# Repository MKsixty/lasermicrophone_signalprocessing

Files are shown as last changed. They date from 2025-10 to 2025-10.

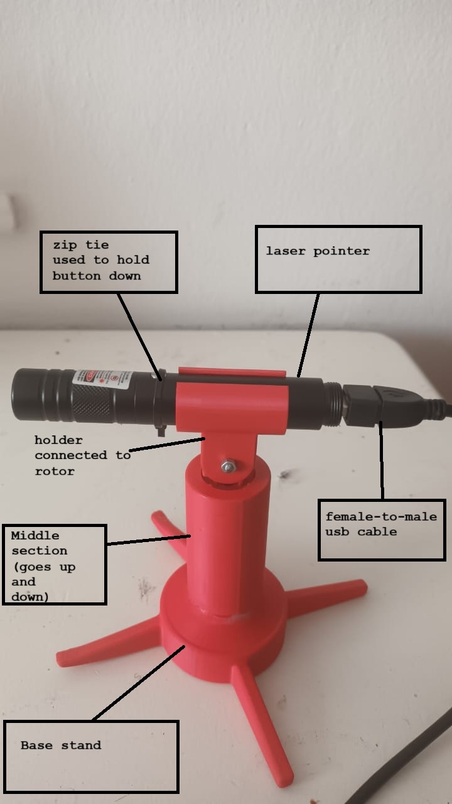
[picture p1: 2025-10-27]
Laser_comp.jpg

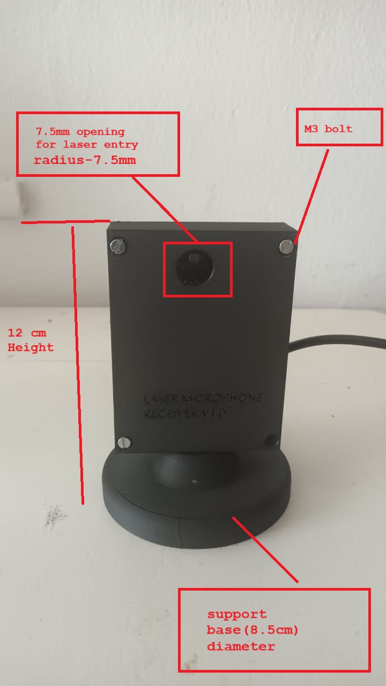
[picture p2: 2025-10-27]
R_front.jpg

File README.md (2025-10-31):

# Laser Microphone Signal Processing Repository

## Overview

This repository contains the complete implementation of a low-cost laser microphone system capable of remotely capturing and reconstructing intelligible speech from vibrating surfaces through optical sensing. The project demonstrates end-to-end acoustic signal recovery using a 650 nm laser transmitter, photodiode-based receiver with dual transimpedance amplifier (TIA) architecture, and multi-stage digital signal processing pipeline.

**Key Achievement**: 15.7-fold intelligibility improvement (STOI = 0.157) with 15.0% Word Error Rate using Whisper Medium transcription on processed audio captured at 1-3 meter distances.

---

## Repository Structure

```
lasermicrophone_signalprocessing/
├── Analysis.m                    # MATLAB signal processing pipeline
├── Laser_MicrophoneV1.py        # Python GUI application with real-time transcription
├── WERcalc.py                   # Word Error Rate calculation utility
├── recordings/                  # Raw and processed audio samples
├── hardware/                    # PCB schematics, 3D models, BOMs
└── docs/                        # Technical documentation and references
```

---

## Hardware Components

### Optical System
- **Transmitter**: BezosMax 650 nm red laser pointer (>5 mW, 2500 m range)
- **Receiver**: BPW34 silicon PIN photodiode (400-1100 nm, 0.6 A/W responsivity @ 650 nm)
- **Reflective Surface**: 3 mm glass window (8.0% reflectivity, superior to Perspex by 0.53 dB SNR)

### Electronics
- **Dual-TIA Architecture**: MCP6292 rail-to-rail op-amps with 10 kΩ feedback resistors
- **Common-Mode Rejection**: Differential amplifier stage (CMRR enhancement for ambient light suppression)
- **ADC Interface**: HiFi USB sound card (48 kHz, 16-bit resolution)
- **Power**: Single 5V USB supply (<500 mA)

### Mechanical
- Custom 3D-printed laser holder with 360° yaw and 90° roll adjustment
- Black PLA receiver enclosure (12 cm height, minimizes optical reflections)

**Total Hardware Cost**: R902 (under R2000 budget constraint)

---

## Software Implementation

### 1. MATLAB Signal Processing (`Analysis.m`)

Multi-stage enhancement pipeline implementing classical DSP techniques:

#### Stage 1: FIR Band-Pass Filtering
```matlab
filter_order = 300;
f_norm = [100 3400] / (fs/2);
b_bp = fir1(filter_order, f_norm, 'bandpass', blackman(filter_order+1));
x_bp = filtfilt(b_bp, 1, x);  % Zero-phase filtering
```
- **Purpose**: Isolate speech band (100-3400 Hz), suppress low-frequency hum and high-frequency sensor noise
- **Window**: Blackman (superior stopband attenuation vs. Hamming/Hann)
- **Implementation**: Zero-phase forward-backward filtering to preserve temporal alignment

#### Stage 2a: Wiener Filter
```matlab
wiener_gain = max(0, 1 - noise_power ./ (frame_power + eps));
wiener_gain = smoothdata(wiener_gain, 'gaussian', 5);  % Musical noise reduction
```
- **Method**: MMSE estimation with noise profile learned from initial 0.5s silence
- **Frame Size**: 20 ms with 50% overlap (Hann window)
- **Smoothing**: Gaussian kernel (5-bin) to suppress musical noise artifacts

#### Stage 2b: Spectral Subtraction
```matlab
cleaned_mag = frame_mag - alpha * noise_spectrum;
cleaned_mag = max(cleaned_mag, beta * noise_spectrum);  % Spectral floor
```
- **Over-subtraction Factor (α)**: 2.0 (aggressive noise removal)
- **Spectral Floor (β)**: 0.001 (prevents excessive attenuation)
- **Window**: Hamming (20 ms frames, 10 ms hop)

#### Stage 2c: Adaptive Spectral Gating
```matlab
snr_estimate = (frame_mag - noise_mean) ./ (noise_std + eps);
gate = 1 ./ (1 + exp(-sensitivity * (snr_estimate - 1)));  % Sigmoid gating
gate = mean(gate_buffer, 2);  % 3-frame temporal smoothing
```
- **Noise Learning**: First 5 seconds (skips initial 30 ms to avoid startup artifacts)
- **Sensitivity**: 2.5 (sigmoid steepness)
- **Soft Gating**: Logistic function for smooth attenuation (vs. hard thresholding)

#### Stage 3: Adaptive Amplitude Restoration
```matlab
% Voice Activity Detection
is_voice = (zcr > 0.03 && zcr < 0.25 && energy > 0.001);

% Gain calculation from original audio
restoration_gain = original_voice_rms / denoised_voice_rms;
restoration_gain = min(restoration_gain, 8.0);  % Limit over-amplification

% Selective amplification
amplified = signal .* (1 + voice_mask * (restoration_gain - 1));
```
- **VAD Criteria**: ZCR ∈ [0.03, 0.25] and energy > 0.001 (25 ms frames)
- **Gain Limiting**: Max 8× to prevent noise re-amplification
- **Normalization**: 99.5th percentile scaling (robust to outlier spikes)

#### Stage 4: Combined Best Approach
Sequential application: Wiener → Spectral Subtraction → Adaptive Restoration
- **Rationale**: Balances smoothness (Wiener), aggressiveness (SpectralSub), and clarity (VAD-based gain)
- **Result**: STOI = 0.157, SNR(VAD) = 3.384 dB, optimal balance across metrics

**Unique Libraries**:
- `signal` (scipy): Butterworth filter design, sosfilt for stable IIR implementations
- `audiowrite`: 48 kHz WAV export for downstream transcription
- `smoothdata`: Gaussian smoothing for musical noise suppression

---

### 2. Python GUI Application (`Laser_MicrophoneV1.py`)

Real-time interface for audio capture, visualization, and transcription.

#### Core Features

**Audio Acquisition**:
```python
stream = p.open(
    format=pyaudio.paInt16,
    channels=1,
    rate=48000,
    input=True,
    input_device_index=device_index,
    frames_per_buffer=1024
)
```
- **PyAudio Integration**: Direct USB sound card interfacing (48 kHz, 16-bit mono)
- **Buffer Management**: 1024-sample chunks for low-latency streaming

**Real-Time Visualization**:
```python
from matplotlib.backends.backend_qt5agg import FigureCanvasQTAgg
self.spectrogram_canvas = MplCanvas(width=8, height=3, dpi=100)
```
- **Waveform Display**: Time-domain amplitude plot with RMS overlay
- **Spectrogram**: STFT-based frequency-time analysis (updated per frame)
- **Dynamic Scaling**: Auto-adjusting axes for signal monitoring

**Speech-to-Text Integration**:
```python
def convert_audio_to_16khz(self, input_file):
    command = ["ffmpeg", "-i", input_file, "-ar", "16000", "-ac", "1", output_file]
    subprocess.run(command, check=True)
```
- **FFmpeg Preprocessing**: Automatic 16 kHz mono conversion for ASR compatibility
- **Multi-Model Support**: 
  - **Vosk** (offline): Small (40 MB), Medium (128 MB), Large (1.5 GB) English models
  - **Google Speech Recognition** (online): Cloud-based via `speech_recognition` library
  - **Whisper** (offline): Small (244 MB), Medium (769 MB) models via `openai-whisper`

**Transcription Workflow**:
```python
model = whisper.load_model('medium')
result = model.transcribe(audio_file, fp16=False)
transcription = result['text'].strip()
```

**GUI Framework**:
- **PyQt6**: Native cross-platform interface with QMediaPlayer for audio playback
- **Tabs**: Recordings management, visualization, transcription settings
- **Configuration**: Device selection, filter parameters, model switching

**Unique Libraries**:
- `pyaudio`: Cross-platform audio I/O (PortAudio wrapper)
- `vosk`: Offline Kaldi-based speech recognition (no internet required)
- `openai-whisper`: Transformer-based transcription (multilingual, robust to noise)
- `speech_recognition`: Google Speech API interfacing
- `matplotlib` + `Qt5Agg`: Embedded plotting in PyQt applications
- `PyQt6.QtMultimedia`: QMediaPlayer/QAudioOutput for WAV playback

---

### 3. WER Calculation (`WERcalc.py`)

Evaluates transcription accuracy using standard Word Error Rate metric:

```python
def calculate_wer(reference, hypothesis):
    ref_words = reference.lower().split()
    hyp_words = hypothesis.lower().split()
    
    # Levenshtein distance via dynamic programming
    d = np.zeros((len(ref_words) + 1, len(hyp_words) + 1))
    # ... matrix computation ...
    
    wer = (substitutions + deletions + insertions) / len(ref_words) * 100
    return wer
```

**Formula**:
$$
\text{WER} = \frac{S + D + I}{N} \times 100\%
$$
where S = substitutions, D = deletions, I = insertions, N = reference word count.

**Usage**:
```python
reference = "the quick brown fox jumps"
hypothesis = "the quack brown fox jumped"
wer = calculate_wer(reference, hypothesis)  # Returns WER percentage
```

---

## Performance Metrics

### Signal Quality (1m Distance, Glass Window)

| Metric | Raw Recording | Combined Processing | Improvement |
|---|---|---|---|
| **STOI** | 0.010 | 0.157 | **15.7× increase** |
| **SNR (VAD)** | 5.305 dB | 3.384 dB | Balanced (post-filtering) |
| **SNR (Noise Floor Est.)** | 14.341 dB | 15.826 dB | +1.485 dB |

### Transcription Accuracy

| ASR Model | Clean Audio WER | Raw Audio WER | Processed WER | Accuracy Gain |
|---|---|---|---|---|
| **Whisper Medium** | 9.09% | 16.46% | **15.0%** | +8.9% absolute |
| **Vosk Large** | 31.2% | 54.79% | 19.16% | +64.98% relative |
| **Google Speech API** | 51.35% | Failed | Failed | Incompatible |

**Key Finding**: Additional Audacity noise reduction (15-17 dB) degraded Whisper Medium performance (21.13% WER), confirming optimal balance achieved by multi-stage pipeline.

### Range Sensitivity

| Distance | SNR (VAD) | STOI | WER (Combined) | Interpretation |
|---|---|---|---|---|
| 1m | 3.384 dB | 0.157 | 15.0% | **Optimal perceptual quality** |
| 2m | 7.531 dB | 0.153 | 15.18% | Balanced |
| 3m | 8.301 dB | 0.085 | 8.11% | **Best ASR (context-driven)** |

**Non-linear Observation**: Higher SNR at 3m due to mean optical power preservation, but STOI degrades from optical diffraction and beam coherence loss. Whisper's language model compensates via contextual inference (lowest WER despite poorest intelligibility).

---

## Installation & Usage

### MATLAB Environment

**Requirements**:
```matlab
% Required Toolboxes:
% - Signal Processing Toolbox
% - Audio Toolbox (for STOI calculation)
```

**Run Processing Pipeline**:
```matlab
% Load recorded audio
[x, fs] = audioread('recordings/1m_glass_raw.wav');

% Load clean reference for SNR/STOI calculation
[clean_ref, ~] = audioread('recordings/clean_reference.wav');

% Execute full pipeline
Analysis;  % Generates stage_1_bandpass.wav through stage_4_combined.wav
```

**Output Files**:
- `stage_1_bandpass.wav`: After FIR filtering (100-3400 Hz)
- `stage_2a_wiener_filtered.wav`: Wiener denoising
- `stage_2b_spectral_subtraction.wav`: Spectral subtraction
- `stage_2c_adaptive_gating.wav`: Adaptive gating
- `stage_3_*_amplified.wav`: Voice-amplified versions
- `stage_4_combined.wav`: **Final optimized output**

### Python Application

**Dependencies**:
```bash
pip install PyQt6 pyaudio numpy matplotlib scipy vosk openai-whisper speech_recognition
```

**FFmpeg Requirement** (for Whisper compatibility):
- **Windows**: Download from [ffmpeg.org](https://ffmpeg.org/download.html), add to PATH
- **Linux**: `sudo apt install ffmpeg`
- **macOS**: `brew install ffmpeg`

**Launch GUI**:
```bash
python Laser_MicrophoneV1.py
```

**Workflow**:
1. **Device Selection**: Choose USB sound card input/output from dropdown
2. **Recording**: Click "Start Recording" → Laser microphone captures audio
3. **Visualization**: Monitor waveform/spectrogram in real-time
4. **Upload Processed Audio**: Load `stage_4_combined.wav` from MATLAB output
5. **Transcription**: Select ASR model (Vosk Large/Whisper Medium recommended) → "Start Transcription"
6. **Export**: Save transcription as `.txt` file

---

## Key Algorithmic Innovations

### 1. Dual-TIA Common-Mode Rejection

**Problem**: Ambient light introduces DC photocurrent offsetting amplifier headroom.

**Solution**: Two TIAs process same photodiode output in opposite polarities. Differential amplifier subtracts common-mode (ambient) while doubling modulated signal:

$$
V_{\text{diff}} = G_d \cdot (V_{\text{TIA1}} - V_{\text{TIA2}}) = G_d \cdot 2 \cdot I_{\text{mod}} \cdot R_f
$$

**Result**: >10 dB ambient noise suppression (CMRR-dependent).

### 2. Hybrid SNR Estimation

**Three Complementary Methods**:

- **Method 1 (Reference-Based)**: Segmented VAD on clean reference, measures residual noise in silence regions after gain compensation
  ```matlab
  snr_ref = 10*log10(signal_pwr_speech / noise_pwr_silence)
  ```

- **Method 2 (Noise Floor)**: First 0.5s assumed noise-only
  ```matlab
  snr_est = 10*log10(mean(signal.^2) / mean(noise.^2))
  ```

- **Method 3 (VAD-Based)**: Energy-based speech/noise classification per frame
  ```matlab
  snr_vad = 10*log10(mean_energy_voice / mean_energy_noise)
  ```

**Insight**: VAD-based SNR most diagnostically valuable—revealed individual filtering stages reduced SNR (1.9-2.6 dB) before adaptive amplification recovered to 3.2-3.9 dB.

### 3. Percentile-Based Normalization

**Problem**: Absolute peak normalization penalizes entire signal for transient spikes.

**Solution**: Use 99.5th percentile of voice regions (identified via VAD) as normalization reference:

```matlab
sorted_voice_abs = sort(abs(voice_signal));
peak_voice_99 = sorted_voice_abs(round(0.995 * length(sorted_voice_abs)));
normalized = signal / peak_voice_99 * 0.98;
```

**Advantage**: Robust to outlier spikes, preserves speech dynamics while preventing clipping.

---

## Hardware Design Files

### PCB Schematics (`hardware/`)
- **KiCad Project**: Dual-TIA receiver with configurable jumpers (JP1-JP4, JPFilter1/2)
- **Gerber Files**: Ready for fabrication (55 mm × 42 mm, 2-layer)
- **Test Points**: TP1-TP6 for oscilloscope debugging

### 3D Models (`hardware/STL/`)
- **Laser Holder**: Base stand, 360° rotor, 90° pitch adjustment
- **Receiver Enclosure**: Black PLA (12 cm height, 7.5 mm photodiode aperture)

### Bill of Materials
- **Electronics BOM**: R902 total (photodiode, op-amps, PCB, USB components)
- **Test Box BOM**: R215 (plywood, glass pane, contact adhesive)

---

## Validation & Reproducibility

### Controlled Test Setup
- **Enclosure**: 20×17.8×25 cm chipboard sound box (sealed with Genkem adhesive)
- **Speaker**: JBL Go 3 (110 Hz - 20 kHz, >85 dB SNR, max volume)
- **Test Audio**: 2-minute monologue from film "Fences" (included in `recordings/clean_reference.wav`)
- **Distances**: 1m, 2m, 3m with fixed alignment

### Objective Metrics
- **STOI**: MATLAB `stoi()` function (0-1 scale, >0.75 = good intelligibility)
- **WER**: Levenshtein distance-based calculation (`WERcalc.py`)
- **SNR**: Three-method validation (reference, noise floor, VAD-based)

---

## Limitations & Future Work

### Current Constraints
- **Range**: 1-3 m operational (optimal 1m for human listening, 2-3m for transcription)
- **Alignment**: Manual beam steering required (no auto-tracking)
- **Processing**: Offline only (MATLAB-based, no real-time embedded DSP)
- **Bandwidth**: 3.4 kHz cutoff excludes sibilants and high-frequency nuances

### Recommended Enhancements
1. **Optical System**:
   - MEMS mirrors or galvanometer steering for adaptive alignment
   - 1550 nm eye-safe laser with silicon APD detection (higher permissible power)

2. **Real-Time Processing**:
   - STM32H7 microcontroller with ARM CMSIS-DSP library
   - Lightweight RNNoise integration for embedded denoising

3. **Advanced Algorithms**:
   - SEGAN (Speech Enhancement GAN) for non-stationary noise
   - Whisper fine-tuning on laser microphone recordings

4. **Environmental Robustness**:
   - Automated calibration via internal reference tones
   - Humidity/temperature compensation for long-term deployment

---

## Citation & Licensing

**Academic Use**:
```bibtex
@misc{mokhakala2025lasermicrophone,
  author = {Mokhakala, Molise},
  title = {Laser-Based Listening Device: Low-Cost Optical Acoustic Sensing with Multi-Stage DSP},
  year = {2025},
  institution = {University of Cape Town, Department of Electrical Engineering},
  url = {https://github.com/MKsixty/lasermicrophone_signalprocessing}
}
```

**License**: MIT (hardware schematics, software code)  
**Hardware Designs**: Open-source (KiCad, STL files freely distributable)

---

## Contact & Support

**Author**: Molise Mokhakala  
**Institution**: University of Cape Town, BSc (Eng) Mechatronics Engineering  
**Supervisor**: Dr. Stephen Paine  

**Issues**: Report bugs or feature requests via GitHub Issues  
**Contributions**: Pull requests welcome for algorithm improvements, ASR model integrations, or hardware optimizations

---

**Acknowledgments**:  
Special thanks to Tsepang (Power Lab technician) for test box fabrication, and Dr. Paine for continuous technical guidance throughout the project.

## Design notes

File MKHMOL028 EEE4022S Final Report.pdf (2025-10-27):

# EEE4022S Research Project

# Final Project Report:

# Laser Based Listening Device

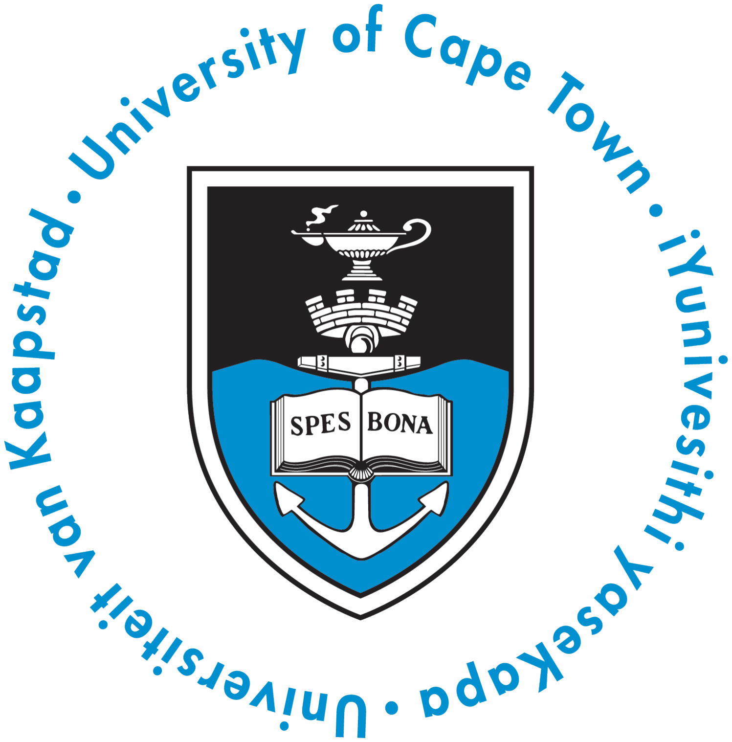
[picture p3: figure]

Prepared by:
Molise Mokhakala

## Prepared for:

Dr Stephen Paine

Department of Electrical and Electronics Engineering

University of Cape Town

Submitted to the Department of Electrical Engineering at the University of Cape Town in partial fulfilment of the academic requirements for a Bachelor of Science degree in Mechatronics Engineering

October 27, 2025

Keywords: laser microphone, optical vibrometry, speech enhancement, transimpedance amplifier, spectral subtraction, Wiener filtering, automatic speech recognition

# Plagiarism Declaration

1. I know that plagiarism is wrong. Plagiarism is to use another’s work and pretend that it is one’s own.
2. I have used the IEEE convention for citation and referencing. Each contribution to, and quotation in, this report from the work(s) of other people has been attributed and properly cited. Any section taken from an internet

source has been referenced to that source.

3. This report is my own work, and is in my own words (except where I have attributed it to others).
4. I have not paid a third party to complete my work on my behalf. My use of artificial intelligence software has been limited to: coding help in VS Code, grammar correction, technical language refinement, and LaTeX formatting assistance.
5. I have not allowed and will not allow anyone to copy my work with the intention of passing it off as his or her own work.
6. I acknowledge that copying someone else’s assignment or essay, or part of it, is wrong, and declare that this is my own work.

Signed:

October 27, 2025

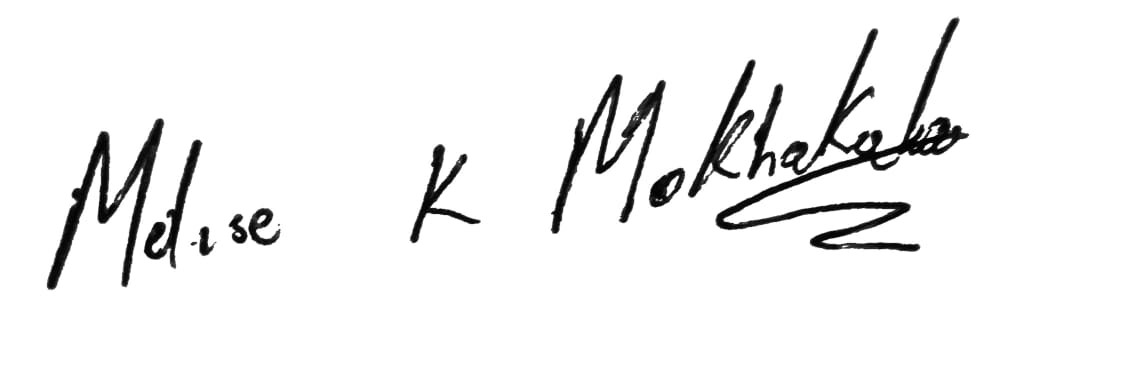
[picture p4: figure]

Molise Mokhakala | Date

Word count: 21793

ii

# Acknowledgements

No man is an island entire of itself; every man is a piece of the continent, a part of the main.
—John Donne

I would like to express my sincere gratitude to Dr. Paine for his continuous guidance, support, and valuable insights throughout this project. His expertise and encouragement were instrumental in its successful completion. I would also like to extend my appreciation to Tsepang, the Power Lab technician student, for his exceptional assistance in developing the test box—an essential component without which none of the experimental results would have been possible

iii

# Abstract

This project presents the design, implementation, and evaluation of a low-cost laser microphone system capable of remotely reconstructing intelligible speech from vibrating surfaces through optical sensing. Sound-induced surface vibrations modulate a 650 nm laser beam reflected from a target window, which is detected by a BPW34 photodiode and converted to electrical signals via a dual transimpedance amplifier (TIA) configuration. The dual-TIA architecture provides enhanced common-mode rejection (CMRR) to suppress ambient light interference,

a critical improvement over single-channel designs. The analog front-end incorporates precision filtering and differential amplification stages, implemented on a custom PCB and powered via a standard 5 V USB interface, achieving a compact and portable form factor suitable for laboratory deployment.

Signal recovery is accomplished through a multi-stage digital signal processing pipeline combining FIR band-pass filtering (100–3400 Hz), Wiener filtering, spectral subtraction, and adaptive voice amplification. This hybrid

approach balances noise suppression with speech preservation, achieving a Short-Time Objective Intelligibility (STOI) score of 0.157—a 15.7-fold improvement over unprocessed recordings. Material characterization revealed that a 3 mm glass window provided 0.53 dB higher SNR than Perspex due to superior optical reflectivity (8.0% vs. 7.8%) and mechanical rigidity. Automatic speech recognition testing using Whisper Medium demonstrated a word error rate (WER) of 15.0% on processed audio at 1 m distance, representing an 8.9% improvement over raw

recordings and validating the system’s practical utility for forensic and surveillance applications.

Range sensitivity analysis at distances of 1–3 m revealed non-linear performance trade-offs: while energy-based SNR increased with distance, perceptual intelligibility (STOI) degraded due to optical diffraction and beam coherence

loss. The system successfully met all design specifications within a budget constraint of R2000, demonstrating that cost-effective laser microphone can achieve sufficient fidelity for automated transcription tasks. The project uses reproducible, open-source implementation integrating modern speech enhancement algorithms with classical optical sensing techniques. All hardware designs, PCB schematics, signal processing code, and experimental datasets are publicly available via GitHub, enabling reproduction and extension by future researchers.It advances the field by providing a reproducible, open-source implementation integrating modern speech enhancement algorithms with classical optical sensing techniques, and establishes quantitative benchmarks for low-cost laser microphone performance across multiple objective metrics.

iv

# Contents

List of Figures | viii
Glossary | ix
1 Introduction | 1
2 Literature Review | 4
3 Methodology | 18
4 System Design and Simulation Analysis | 22

v

Contents

4.2 System Requirements and Specifications | | 22
4.2.1 | Requirements | | 22
4.2.2 | Specifications | | 23
4.3 Design Outline | | 24
4.4 System Overview | | 24
4.5 Hardware Design Process Overview | | 24
4.5.1 | Digitisation and Processing Hardware Comparison | | 28
4.5.2 | Receiver Circuit Implementation — component calculations and selection | | 29
4.5.3 | Mechanical Laser Holder Design | | 33
4.5.4 | PCB Design and Layout | | 34
4.6 Final Hardware Prototype Implementation | | 38
4.7 Testing Methodology and Validation Approach | | 39
4.7.1 | Experimental Setup | | 39
4.7.2 | Measurement Procedure | | 42
4.7.3 | Validation Framework | | 42
4.7.4 | Summary of Methodology | | 42
5 Signal Processing Theory and Implementation | 43
5.1 Overview | | 43
5.2 Signal Model | | 43
5.3 Digital Signal Processing Environment | | 43
5.4 Preprocessing and FIR Band-Pass Filtering | | 43
5.5 Bandwidth Limitation | | 44
5.6 Preprocessing and FIR Band-Pass Filtering in MATLAB | | 44
5.7 Denoising techniques: Wiener and Spectral Subtraction Filtering | | 46
5.7.1 | Wiener Filter Algorithm | | 46
5.7.2 | Spectral Subtraction Algorithm | | 47
5.7.3 | Comparative Evaluation | | 47
5.8 Speech-to-Text Translation | | 49
5.8.1 | Model Selection and Design Rationale | | 50
5.8.2 | Audio Preprocessing for Compatibility | | 50
5.8.3 | Evaluation and Observations | | 52
5.8.4 | more noise reduction | | 52
5.9 Improvement | | 52
5.9.1 | Python Integration and Real-Time Interface | | 52
6 Results | | 54
6.0.1 | Material Comparison: Perspex(Acrylic) vs. Glass Window | | 54
6.0.2 | SNR calculation | | 54
6.1 detection and filtering results | | 55
6.1.1 | method | | 55
6.1.2 | Method:STOI | | 56
6.1.3 | results | | 56
6.2 Speech-to-Text Results | | 58
6.3 Range Sensitivity | | 59

vi

Contents

6.3.1 | Method | | 59
6.3.2 | Results | | 60
6.3.3 | Range Sensitivity Analysis | | 60
7 Discussion | | 61
8 Conclusion | | 63
9 Recommendations | 64
A appendix | | 69
A.1 Code and Data Repository | | 69
A.2 Receiver simulation circuits | | 69
A.3 receiver full pcb schematic | | 69
A.4 Bill of Materials | | 71
A.5 matlab Combined processing code snippet | | 72
A.6 The processing stages waveforms and spectrograms | | 76
A.7 SNR calculation code | | 76
A.8 AI prompts and responses | | 78

vii

# List of Figures

2.1 Laser_beam divergence and convergence due to window vibration | | 5
3.1 The overview of all the project stages | | 18
3.2 Iterative development flow diagram illustrating the requirement-driven progression through design
stages with feedback loops for refinement and validation | 20

4.1 High-level architecture of the laser microphone receiver, showing the optical detection, acquisition,
and DSP subsystems | 24
4.2 Transimpedance amplifier converting photodiode current into a voltage signal for optical-to-electrical
interfacing | 26
4.3 Dual transimpedance amplifier (TIA) configuration used to improve common-mode rejection and
reduce ambient light interference | 29
4.4 Buffered voltage reference and AC-coupled amplifier stage with gain of 2 (20k/10k) using LM358
op-amps. The circuit replacing just the ac coupled buffer | 32
4.5 Exploded render of the 3D-printed mechanical laser holder assembly showing (a) the base stand, (b)
the rotor section, and (c) the laser holder with a firm grip on the 18mm diameter laser case . . . . 33

4.6 the laser holder showing the stand, rotor, and laser mounted together. This set up gives the laser a maximum height of 15cm based on the adjustment of the middle which can be rotated up or down 34 4.7 PCB design views showing the overall layout (left) and detailed layer breakdowns (right). The

configuration highlights the analog front-end placement, ground-plane strategy, and component
accessibility | 37
4.8 Final 3D-printed enclosure and mounting stand for the laser microphone receiver, fabricated from black PLA with a total height of 12 cm and base diameter of 8.5 cm. The labelled features highlight
design details including component alignment, cable routing, and surface openings | 40
4.9 Test setup for validation of the laser microphone receiver: 3 mm glass window mounted on wooden
sound enclosure with internal JBL Go 3 loudspeaker source | 41

5.1 Comparison of time-domain (left) and frequency-domain (right) characteristics for the 1 m test. The

raw audio amplitude is generally lower than the clean reference, except for a spike near 20 s, which reduces the overall audibility of the laser microphone signal. In the spectrogram, the noisy signal maintains higher power levels (70–80 dB, dark blue) up to 3.5–4 kHz for most of the two-minute duration, while the clean reference remains around 50 dB (cyan), indicating high-frequency noise

contamination in the recorded signal | 44

6.1 Signal-to-Noise Ratio (SNR) comparison using three estimation methods: Clean Reference, Noise
Floor, and Voice Activity Detection (VAD) | | 56
A.1 receiver simulation circuit adding the last amplifier stage | | 69
A.2 PCB receiver schematic | | 70
A.3 The waveforms and the spectrogram of all the audio enhancement stages before adaptive amplification 76
A.4 Waveforms and the spectrograms after adaptive amplification | | 76
A.5 creating a table | | 79

viii

List of Figures

A.6 Promp1 | | 79
A.7 Promp1 | | 79
A.8 Promp3 | | 80
A.9 Prompt2 response | | 80

ADC
Analog-to-Digital Converter – A device that converts an analog signal into its corresponding digital represen-

tation.

ASR
Automatic Speech Recognition – A technology that converts spoken language into text using machine learning

or signal processing algorithms.

BOM
Bill of Materials – A comprehensive list of all components required for hardware assembly.

CMRR
Common-Mode Rejection Ratio – A measure of an amplifier’s ability to reject common-mode signals, i.e.,

noise appearing simultaneously on both inputs.

DAC
Digital-to-Analog Converter – A circuit that converts digital values into continuous analog signals.

DSP
Digital Signal Processing – The numerical manipulation of signals, typically using algorithms to enhance, analyze, or transform data.

FIR
Finite Impulse Response – A type of digital filter with a finite duration impulse response, known for linear

phase properties.

He–Ne Laser
Helium–Neon Laser – A gas laser operating typically at 632.8 nm, used for precise optical measurements due

to its narrow linewidth and coherence.

IIR Infinite Impulse Response – A recursive digital filter type that uses feedback to achieve a desired frequency

response.

LD Laser Diode – A semiconductor device that emits coherent light when forward biased.

LDV
Laser Doppler Vibrometer – A non-contact device that measures surface vibration by detecting the Doppler shift of reflected laser light.

PCB
Printed Circuit Board – A board that mechanically supports and electrically connects electronic components

using conductive tracks and pads.

ix

List of Figures

PIN Photodiode
Positive–Intrinsic–Negative Photodiode – A semiconductor light sensor with fast response and low noise

characteristics.

SNR
Signal-to-Noise Ratio – The ratio between the desired signal power and the background noise power, expressed in decibels (dB).

STOI
Short-Time Objective Intelligibility – A quantitative metric (0–1 scale) assessing the intelligibility of processed

or degraded speech signals.

TIA
Transimpedance Amplifier – An operational amplifier circuit that converts input current (from a photodiode)

into a proportional output voltage.

VCSEL
Vertical-Cavity Surface-Emitting Laser – A semiconductor laser that emits light perpendicular to its surface, often used for compact optical systems.

WER
Word Error Rate – A standard metric for evaluating automatic speech recognition accuracy by comparing predicted text to a reference transcript.

Wiener Filter
– An adaptive filter that minimizes the mean-square error between estimated and desired signals, commonly used for noise reduction.

Whisper
– An open-source speech-to-text model by OpenAI designed for multilingual transcription and robust performance in noisy audio.

Window Reflectivity
– The proportion of light reflected from a window’s surface, influencing the strength of optical feedback in laser microphones.

Photodiode
– A semiconductor device that converts light into an electrical current proportional to the incident optical

power.

x

# Chapter 1

# Introduction

This report details the research, design, and development of a laser-based listening device referred to as a laser microphone in the paper, focusing on the hardware, optical, and signal processing components required to reconstruct audio from distant vibrating surfaces. The study aims to implement a functional prototype capable of capturing and processing acoustic information through non-contact optical sensing. The project was undertaken as part of the final year BSc (Eng) Mechanical Engineering degree in the Department of Electrical and Electronic

Engineering at the University of Cape Town.

## 1.1 Background to the Study

Sound detection using light-based methods has become an emerging field of interest due to its ability to capture acoustic information without direct physical contact. Conventional microphones, although effective, are limited by distance, environmental noise, and the need to be close to the sound source.

Laser-based acoustic sensing provides a non-contact alternative by exploiting the minute vibrations induced on a reflective surface by sound waves. A coherent laser beam directed at the surface captures these vibrations through optical interference, which can then be processed into an audible signal. Early research into laser microphones has demonstrated their potential in surveillance, industrial monitoring, and structural diagnostics, but challenges remain to achieve reliable, noise-resistant, and cost-effective implementations.

This project builds on existing research by designing and testing a laser microphone system tailored for remote acoustic signal acquisition. The focus is on creating a practical laboratory-scale prototype capable of detecting and reconstructing speech or sound signals reflected off common surfaces, using photodiode-based sensing and digital signal processing algorithms for reconstruction.

## 1.2 Problem Statement and Objectives of this Study

Problem Statement: Despite decades of development in laser listening technology for covert surveillance and remote acoustic sensing, practical implementations remain constrained by high costs[1], low signal-to-noise ratios

due to weak optical modulation and ambient interference, and limited accessibility for research applications. Existing systems either sacrifice real-world applicability for laboratory sensitivity or require specialised optical equipment beyond typical engineering budgets. This project addresses the fundamental challenge of whether integrated optical-electronic-algorithmic design can achieve transcription-grade speech intelligibility (WER <20%, STOI >0.15) from a low-cost (<R2000) laser microphone system operating at practical distances (1–3 m) on

common reflective surfaces, while maintaining reproducibility through open-source implementation suitable for forensic, surveillance, and academic applications.

### 1.2.1 Problems to be Investigated

The primary issues to be investigated in this study include:

1.3. Scope, Limitations and Assumptions
- Determining the effectiveness of a laser-based microphone system in reconstructing acoustic signals from a vibrating surface.
- Evaluating how different surface materials, distances, and environmental conditions affect signal accuracy and sensitivity.
- Designing an optical receiver system capable of translating laser reflections into usable electrical signals.
- Implementing digital signal processing algorithms for noise reduction, filtering, and intelligible sound reconstruction.
- Implement a transcription model as part of the device.
- Assessing system limitations, including range and surface profile.

### 1.2.2 Purpose of the Study

The purpose of this study is to develop and experimentally validate a laser-based listening device capable of converting surface vibrations into audible signals. The motivation arises from the potential applications of optical acoustic sensing in security surveillance, industrial inspection, and scientific experimentation. By investigating this approach, the study seeks to bridge theoretical understanding and practical implementation of laser vibrometry for acoustic reconstruction.

The significance of this research lies in demonstrating a proof-of-concept that utilises electronic principles, optical sensing, signal processing, and embedded system design to explore an innovative method of sound detection. The outcomes will provide valuable insights into signal quality optimisation, cost-effective design strategies, and environmental robustness for future implementations.

## 1.3 Scope, Limitations and Assumptions

### 1.3.1 Scope

The scope of this project includes:

- Theoretical and experimental investigation of optical vibration detection for sound reconstruction.
- Design and construction of a laser-based sensing system using commercially available components.
- Implementation of analogue front-end circuitry for photodiode signal conditioning.
- Development of digital signal processing algorithms in MATLAB to reconstruct and evaluate the detected

signals.

- Performance evaluation under controlled laboratory conditions and transcription intelligibility.

### 1.3.2 Limitations

The limitations of this study include:

- The experimental setup is limited to short-range indoor measurements (up to a few meters).
- Environmental disturbances such as air turbulence, background light, and mechanical vibrations may affect measurement accuracy.

1.4. Plan of Development
- The project is constrained by the available budget and laboratory resources, with the budget capped at R2000.
- Real-time embedded processing was not implemented in this phase; signal analysis was conducted offline using MATLAB.
- The study assumes a coherent and stable laser source with negligible beam divergence over the test distance.

## 1.4 Plan of Development

The report begins by introducing the underlying principles of optical sound detection and prior research on laser vibrometry and acoustic signal reconstruction. Chapter 2 presents a comprehensive literature review on laser-based sensing systems and relevant digital signal processing techniques.

Chapters 3 and Chapter 4 outlines the methodology adopted for the hardware and optical design, detailing component selection, circuit implementation, and system integration. Chapter 5 discusses the digital signal processing workflow, including noise reduction, filtering, and time-domain signal reconstruction. This chapter also shows implementation of a translation model and its assessment against other models.

Chapter6 then quantifies the system performance across the dectection, signal processing and transcription domains

The report concludes with a discussion of the system’s performance, limitations, and recommendations for further development, including real-time processing and enhanced environmental robustness.

# Chapter 2

# Literature Review

This chapter situates the laser microphone project within a broader research and technological context by surveying the relevant literature. Although the basic concept of recovering sound from optical vibrations has existed for decades, its applications in both security and scientific settings present unique challenges and opportunities. Rather than simply duplicating past designs, this project aims to critically assess existing methods and technologies to inform the development of a system tailored for modern use cases, including remote surveillance, acoustic sensing, and machine learning–based audio reconstruction.

The objective of this review of the literature is therefore not only to outline technical precedents but also to identify the motivations, limitations, and innovations that have shaped this field. Particular emphasis is placed on the challenges associated with optical signal acquisition and noise suppression, especially in uncontrolled environments where ambient disturbances can dominate the true audio signal.

The chapter begins by reviewing existing implementations of laser microphone systems, ranging from intelligencegrade surveillance tools to academic and hobbyist prototypes. Then it delves into the photonic components that form the heart of such systems, namely lasers, photodetectors, and transimpedance amplifiers, highlighting performance trade-offs and noise sources. Following this, a detailed discussion of signal acquisition and processing challenges is presented, with a focus on the nature of optical vibrometry signals and the types of interference commonly encountered in this context.

To address these challenges, Section 5 reviews the traditional filtering and enhancement techniques used in optical audio processing pipelines. This is followed by a review of emerging machine learning–based methods, which promise more adaptive and robust denoising in complex environments. Finally, relevant research sources are cited to provide a roadmap for further exploration and benchmarking, setting the stage for the technical implementation that follows.

In doing so, this chapter aims to provide both a theoretical foundation and practical motivation for the system design choices made in subsequent stages of the project.

## 2.1 Overview and History of Laser Microphones

Laser microphones, also referred to as laser interferometers, laser vibrometers, or laser accelerometers, are non-contact devices that detect vibrations on a surface caused by sound waves. By directing a coherent light beam, typically a laser, onto a reflective surface such as a glass window, minute deflections caused by acoustic pressure modulate the reflected beam. This modulated light is then converted into an electrical signal using a photodetector, effectively reconstructing the original audio waveform [2]. The human voice typically occupies the 300 Hz–3400 Hz range, which falls comfortably within the operational bandwidth of modern laser microphone systems [3].

The concept of transmitting or detecting sound via light predates the invention of the laser. In the 1880s, Alexander Graham Bell developed the photophone, which transmitted speech using a modulated beam of sunlight reflected

2.1. Overview and History of Laser Microphones

from a vibrating diaphragm onto a selenium cell receiver whose electrical resistance varied with light intensity. Bell considered this device even more significant than his telephone, describing it as capable of revealing “discoveries undreamed of just now” [4]. His work laid the foundation for photoacoustic and photothermal detection methods

that underpin modern optical communication and remote acoustic sensing.

The first practical use of light for covert listening emerged decades later in 1947, when Léon Theremin developed the Buran system in the Soviet Union. Instead of a laser, it employed a low-power infrared beam to detect sound-induced vibrations in window glass at distances of up to 500 m. The system, reportedly used by the KGB to surveil U.S., British, and French embassies in Moscow, is widely regarded as the precursor to the modern laser microphone [5]. By the 1990s, advancements in laser diodes, optical detectors, and signal processing revived

interest in laser-based eavesdropping systems, though their popularity later declined with the advent of digital and network-based surveillance technologies.

Operation In operation, laser eavesdropping relies on the fact that acoustic pressure waves cause solid surfaces—such as windows, cups, or walls—to vibrate. When a laser beam is reflected off such a surface, these vibrations induce phase and amplitude modulations in the reflected light. A remote receiver converts these modulations back into an audio signal. According to FCDO Services [1], this allows stand-off listening from distances exceeding 500 m

without physical intrusion, making it a preferred technique for technical surveillance due to its low detectability.

Moses and Trout [4], describe a simplified academic demonstration of this principle, where a low-cost laser pointer

and solar cell were used to reproduce the sound reflected from a vibrating window. In this setup, fluctuations in the curvature of the glass surface altered the divergence of the reflected beam, creating measurable intensity variations at the photodetector. Even minimal window vibrations produced audible signals after amplification, effectively mimicking the operation of professional-grade surveillance systems.

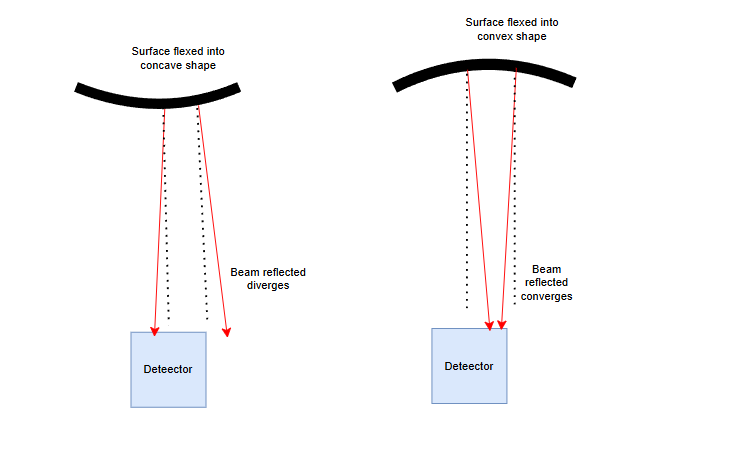
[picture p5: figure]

Figure 2.1: Laser_beam divergence and convergence due to window vibration

Modern laser microphone technology has evolved significantly beyond its espionage origins. Contemporary implementations employ advanced receivers, low-noise amplifiers, and digital demodulation techniques, including double-heterodyne detection, to enhance sensitivity and suppress noise. High-end interferometric systems can now detect sub-nanometer vibrations, with documented sensitivity down to angstrom-scale displacements, and operate under challenging conditions such as fog or poor visibility [6]. Commercial laser vibrometers, originally designed

for precision vibration analysis in engineering and materials testing, are conceptually similar to laser microphones and can be repurposed for acoustic monitoring, structural health assessment, or surveillance applications. .

2.2. Review of Existing Laser Microphone Systems

## 2.2 Review of Existing Laser Microphone Systems

Research into laser microphones has a range of system designs that differ in their underlying optical principles, component choices, and intended applications. Early efforts were closely linked to the development of laser Doppler vibrometers (LDVs), which exploit the Doppler effect to measure vibration velocity from reflected light. Cai [7]

demonstrates that the frequency shift between reference and reflected beams could be directly related to surface vibration velocity, enabling non-contact audio capture. Interferometric techniques such as scanning Laser Doppler Vibrometry (LDV) have also been employed to visualise sound fields non-intrusively by detecting refractive index variations in air [8][9] [10]. Such systems demonstrate the same optical phase modulation principle underlying

modern laser microphones. While LDVs are highly sensitive, their reliance on coherent, mirror-like reflective surfaces limits deployment in practical settings where surfaces are rough or non-ideal. This highlights a recurring trade-off in laser microphone research: systems with high sensitivity often lack robustness in uncontrolled environments.

Alternative approaches leverage pulsed laser vibrometers (PLVs). Wang et al. [11] proposes a pulsed laser system coupled with photo-electromotive force (photo-EMF) sensors, incorporating multiple reflections of the probe beam

to amplify the signal before detection. This design achieved higher sensitivity than conventional vibrometers, but at the cost of increased optical complexity and alignment challenges. The need for stable beam redirection across multiple bounces raises questions about system scalability and robustness outside laboratory conditions.

A third class of designs is based on the self-coupling effect of laser diodes (LDs), where variations in refractive index caused by acoustic pressure modulate the laser’s own wavelength. Daisuke [12] reports that this approach,

using a distributed feedback LD with integrated photodiode detection, provided improved sensitivity compared to traditional vibrometry. Importantly, the self-coupling method reduces the reliance on external interferometers, making it potentially more compact and cost-effective. However, performance still heavily depends on surface reflectivity and environmental stability, raising concerns about reproducibility under different operating conditions.

Commercial systems have also emerged, often marketed as invasive or semi-invasive monitoring devices. For example, Argo’s multi-use infrared stethoscope system incorporates a laser microphone option for room surveillance, offering wide field of view monitoring and AM audio transmission at 840 nm argo. While such designs demonstrate practical integration, their technical specifications—such as wideband coverage and eye safety compliance—are rarely reported in detail, making independent evaluation difficult. Moreover, their use of infrared wavelengths prioritises surveillance robustness over high-fidelity sound reproduction, reflecting a divergence between commercial and academic design priorities.

A further commercial example is the PKI 3000 Laser Microphone by PKI Electronic Intelligence [13]. It employs an eye-safe 1550 nm Class 1 laser (< 10 mW) and an integrated interferometric receiver to extract speech information

from Doppler shifts in the backscattered beam. Unlike earlier systems limited by reflection angle, the PKI 3000 achieves greater angular independence and can operate through closed glass surfaces at distances of 5 – 150 m. The device includes a built-in low-light CCD camera for alignment and selectable bandwidths between 150 Hz – 7 kHz, with analog and digital outputs for recording or monitoring. Though PKI notes higher-end variants (PKI 3100/3200) yield better audio quality, the PKI 3000 demonstrates a practical, field-ready implementation that

integrates optical, electronic, and acoustic processing within a single portable unit, highlighting how commercial designs trade fidelity for deployability.

Across these systems, thematic contrasts emerge. LDV- and PLV-based systems prioritise sensitivity but require ideal reflective surfaces and precise alignment, whereas self-coupling LD systems sacrifice robustness for compactness and lower cost. Commercial implementations emphasize operational feasibility over academic metrics such as

2.2. Review of Existing Laser Microphone Systems

signal-to-noise ratio (SNR) or distortion.The optical source and receiver subsystem largely determines system

performance. Laser wavelength, coherence length, power output, photodetector sensitivity, and bandwidth directly influence SNR, dynamic range, and environmental robustness. While early systems relied on gas lasers for coherence stability, advances in semiconductor laser diodes and integrated photonics now enable more compact, energy-efficient, and eye-safe field-deployable designs

### 2.2.1 Laser Source Selection

Traditional laboratory-grade systems typically employ Helium–Neon (HeNe) lasers at 632.8 nm due to their narrow linewidth and high coherence length, ideal for interferometric detection and phase-sensitive vibrometry [9]. However,

such lasers are bulky and power-hungry, limiting their portability. Modern alternatives favour semiconductor-based sources, including distributed feedback (DFB) and vertical-cavity surface-emitting lasers (VCSELs), which provide

tunable wavelengths, compact form factors, and stable output suitable for self-coupling and heterodyne detection schemes [7], [12].

### 2.2.2 Wavelength Considerations

Several studies emphasise that the type of laser diode employed can significantly affect signal capture fidelity. Distributed-feedback (DFB) laser diodes are commonly used due to their narrow linewidth and wavelength stability, which enhance sensitivity to minute surface vibrations [12]. However, their relatively high cost and power

consumption may limit applicability in compact or low-budget systems. Conversely, standard edge-emitting laser diodes are more cost-effective but suffer from broader linewidths and reduced coherence, limiting their performance in interferometric setups.

The selection of operating wavelength also introduces critical trade-offs. Infrared wavelengths around 850 nm are commonly deployed in commercial systems for surveillance, partly because they balance eye safety, availability of components, and adequate reflectivity across common window glass materials argo. However, studies have demonstrated that longer wavelengths, such as 1550 nm, offer improved eye safety margins for higher power operation, albeit at the cost of reduced efficiency in some photodetectors [14]. Moreover, shorter wavelengths (e.g., 633 nm He-Ne lasers) may achieve higher sensitivity due to reduced speckle size on target surfaces, but their increased scattering makes them less robust in outdoor or turbulent conditions [15]. These wavelength-dependent

trade-offs highlight the absence of a universally optimal solution, with system design often reflecting specific application constraints.

### 2.2.3 Photodetectors and Transimpedance Amplifier (TIA) Design

High-speed photodiodes combined with low-noise transimpedance amplifiers (TIAs) form the core of most laser

microphone receiver architectures. The photodiode must provide sufficient bandwidth to cover the acoustic range (20 Hz–20 kHz) while maintaining a low noise-equivalent power (NEP) for adequate signal-to-noise ratio (SNR). Avalanche photodiodes (APDs) offer internal gain and enhanced sensitivity compared to PIN types but introduce excess multiplication noise and require higher bias voltages [16], [17], [18].

The TIA stage plays a central role in determining overall system noise and stability. As Carter notes, “Noise is a purely random signal that cannot be completely eliminated, but its effects can be minimized through careful circuit design” [19]. In a TIA, dominant sources include op-amp voltage and current noise, as well as the thermal (Johnson) noise of the feedback resistor. According to Carter, “the total output noise is the root-sum-square of the

voltage and current noise contributions,” and the total input capacitance forms a pole with the feedback impedance,

2.3. Signal Acquisition and Noise Challenges

limiting bandwidth and affecting stability [19].

Thus, increasing the feedback resistor improves gain but raises thermal noise, revealing an inherent trade-off between sensitivity, bandwidth, and noise. When coupled with high-capacitance photodiodes, wideband TIAs must balance these parameters carefully. Recent CMOS implementations demonstrate sub-pA/√
Hz noise levels and
MHz-range bandwidths, enabling compact, low-noise front ends for laser-based acoustic sensing [17], [20].

Taken together, the literature reveals that laser microphone component selection involves balancing competing requirements: wavelength choice affects safety, reflectivity, and coherence; photodiode selection trades sensitivity against noise; and TIA design must optimise bandwidth while minimising thermal and shot noise. Despite these

insights, comparative experimental studies remain scarce. Most reports evaluate component choices in isolation rather than benchmarking across full system performance. Consequently, it is still unclear which combinations of laser wavelength, detector type, and amplifier topology yield the most robust results in practical acoustic sensing scenarios. Addressing this gap would require standardised testing protocols that account for both controlled

laboratory conditions and variable real-world environments.

## 2.3 Signal Acquisition and Noise Challenges

Noise reduction remains one of the most critical and persistent challenges in the development of laser microphone systems. The issue arises from the fact that noise sources are highly variable across environments and application contexts, and they often change dynamically over time. As Chen [21] notes, early work on speech enhancement

can be traced back to patents in the 1960s, where analogue implementations of spectral subtraction were first described. Although these methods introduced foundational concepts for suppressing additive noise, subsequent decades have shown that no single approach provides robust performance under all conditions.

A key difficulty is the diversity of noise sources affecting laser microphones. Mechanical vibrations and wind contribute low-frequency distortions, while optical noise is introduced through laser jitter and surface roughness of the reflective target. Electronic noise sources, including thermal noise in photodiodes and shot noise, further degrade the acquired signal. Cai [7] emphasised that surface characteristics strongly affect signal quality: rough or non-uniform surfaces scatter light irregularly, leading to reduced signal-to-noise ratio (SNR) and limiting fidelity at higher acoustic frequencies. Daisuke [22] further reported that many laser microphone systems produce SNRs that

are too low for practical recording, highlighting a significant gap between laboratory feasibility and application-level performance.

Multiple strategies have been explored to address these challenges. Physical approaches, such as increasing the number of microphones in an array, allow for beamforming and spatial filtering [21]. However, in most scenarios

only a single optical channel is available, restricting the use of such methods. Traditional digital techniques, including Wiener filtering and spectral subtraction, offer relatively low computational complexity but introduce trade-offs between noise suppression and speech distortion. For instance, Wiener filters reduce noise effectively under stationary conditions but degrade intelligibility when noise is highly nonstationary [23]. Similarly, spectral

subtraction methods perform well in moderate noise but often produce musical noise artifacts in real-world environments [24].

These limitations underscore an unresolved debate in the literature: whether the focus of laser microphone noise reduction should prioritise intelligibility (e.g., for surveillance applications), fidelity (e.g., for recording and archival purposes), or robustness (e.g., for deployment in uncontrolled environments). Each objective demands different trade-offs in filter design, and attempts to optimise one dimension often degrade another. Chen [21] argues that

2.4. Signal Acquisition and Noise Challenges

this “triple constraint” of noise reduction, intelligibility, and naturalness remains a fundamental bottleneck across speech enhancement systems, and laser microphones inherit this challenge in amplified form due to their inherently low SNR.

Overall, while numerous techniques have been developed to ameliorate noise in laser microphone systems, the literature reveals a persistent gap: few comparative studies evaluate algorithms under standardised benchmarks or realistic field conditions. Without consistent metrics and datasets, it remains difficult to determine which acquisition and filtering approaches best translate from theory to practical deployment.

## 2.4 Signal Acquisition and Noise Challenges

Signal acquisition in laser microphones is uniquely difficult because the desired acoustic signal is typically weak and easily masked by multiple sources of noise. Unlike conventional microphones, which rely on direct pressureto-voltage transduction, laser microphones must infer acoustic vibrations indirectly through optical reflections. This multi-stage process introduces mechanical, optical, and electronic noise, all of which complicate robust audio capture.

### 2.4.1 Noise Sources

Noise in laser microphone systems can be broadly classified into three categories. First, mechanical noise includes vibrations from mounts, air turbulence, or wind, which couple into the reflective surface and distort the recovered signal. Second, optical noise arises from speckle effects, surface roughness, and laser jitter, which cause fluctuations in the reflected beam [7]. Third, electronic noise is generated within the photodetection Cain, including shot

noise, dark current, and thermal noise in photodiodes and transimpedance amplifiers. The combination of these noise sources often results in low signal-to-noise ratios (SNR), a limitation repeatedly cited as preventing laser microphones from achieving recording-quality audio [22].

### 2.4.2 Historical and Conventional Approaches

Noise suppression has been a focus of acoustic research for decades. Chen [21] traced early speech enhancement

methods to Schroeder’s patents on analogue spectral subtraction in the 1960s. While such approaches provided foundational tools for noise removal, they assumed stationary additive noise, an assumption rarely satisfied in real-world optical vibrometry. Subsequent studies demonstrated that single-channel algorithms such as Wiener filtering and spectral subtraction could reduce noise effectively in controlled conditions, but at the expense of introducing speech distortion when the noise environment was nonstationary [23], [24].

Invasive alternatives, such as integrating contact stethoscopes with optical receivers (e.g., Argo surveillance systems argo), have been used as fallback solutions to mitigate signal loss when optical paths are obstructed. While

effective in specific contexts, these designs compromise the defining non-contact advantage of laser microphones, highlighting the difficulty of balancing robustness and fidelity.

### 2.4.3 Methodological Tensions

A persistent tension in the literature concerns the trade-offs between intelligibility, fidelity, and robustness. For surveillance-oriented applications, intelligibility of speech is often prioritised over naturalness of sound, whereas high-fidelity recording applications require preservation of acoustic detail beyond 15 kHz. Chen [21] argued that

these objectives cannot be simultaneously optimised with conventional filtering, leading to what he describes as a

2.5. Filtering and Signal Enhancement Techniques

“triple constraint.” In laser microphones, this problem is exacerbated by inherently weaker signals compared to direct-contact microphones, making traditional techniques less effective.

## 2.5 Filtering and Signal Enhancement Techniques

Filtering and signal enhancement are central to the viability of laser microphones, as they determine whether the weak, noise-corrupted optical signals can be transformed into intelligible audio. Over the past decades, both classical signal processing methods and modern machine learning (ML) approaches have been proposed. This

section critically reviews these techniques, highlighting methodological strengths, contradictions, and research gaps.

### 2.5.1 Traditional Filtering Techniques

Traditional approaches form the first line of defence in most laser microphone systems, typically applied in analogue circuitry or as post-ADC digital processing.

Analog Filtering

Analogue pre-processing stages, such as low-pass, band-pass, and notch filters, are often integrated within transimpedance amplifier (TIA) circuits to suppress high-frequency noise and prevent aliasing prior to digitisation. Cai [7] demonstrated that reducing high-frequency optical jitter using analogue low-pass filtering improved SNR

in laser Doppler vibrometry setups. However, such filtering is inherently rigid, offering limited adaptability to time-varying acoustic or environmental conditions.

## 2.6 Digital Filtering (Post-ADC)

Digital FIR and IIR Filtering

Post-ADC, finite impulse response (FIR), and infinite impulse response (IIR) filters are widely employed. FIR

filters preserve linear phase and are effective for speech-band isolation, while IIR filters are computationally efficient but may distort phase [25]. Case studies using equiripple FIR bandpass designs between 100 Hz and 4.5 kHz demonstrated effective suppression of electrical hum and low-frequency noise [26] . Yet, the computational cost of

high-order FIR filters remains a concern for real-time applications.

Comb and Adaptive Filters

Periodic noise, such as power line hum or mechanical resonances, is often addressed using comb filters or ALE methods. Adaptive notch structures have been shown to eliminate harmonic noise efficiently, but their performance degrades when the target speech signal lies near the noise harmonics, requiring high filter orders [21]. Comb

filters offer a simpler alternative but must be tuned carefully to avoid distorting broadband speech components. MATLAB, SciPy, CMSIS-DSP can be used to implement the aforementioned filters.

Spectral Subtraction and Wiener Filtering

Spectral subtraction, a technique first patented by Schroeder and later expanded in Chen’s work [24], assumes

additive, quasi-stationary noise and removes it by estimating noise spectra during silence. While effective in moderate noise conditions, this approach often produces “musical noise” artifacts in nonstationary settings. Wiener filtering provides a theoretically optimal linear solution in the mean-square error sense, but its performance depends

2.6. Digital Filtering (Post-ADC)

heavily on accurate estimation of noise and speech spectra. Benesty et al. [23] highlighted the trade-off: maximising

noise reduction typically introduces significant speech distortion. Widely linear Wiener filters have been proposed to reduce distortion by exploiting conjugate symmetry in speech signals [27], yet they remain computationally complex. Sager et al. [26] demonstrates that a combination of spectral subtraction and gating with gating used

right after the spectral subtraction, resulted in a significant reduction in noise than when just spectral subtraction is used. This brings.

Kalman and Wavelet-Based Filtering

Kalman filters model the audio signal as a dynamic system and are particularly effective under time-varying noise conditions, but they require accurate state-space models, which are difficult to obtain in optical-acoustic contexts [21]. Wavelet denoising provides a time-frequency localised alternative, excelling at suppressing transient noise

while preserving speech onsets. However, the choice of wavelet basis critically affects performance, and there is little consensus on optimal configurations for laser microphones.

### 2.6.1 Machine Learning-Based Approaches

More recently, machine learning methods have been introduced to overcome the rigid assumptions of traditional filtering.

Deep Neural Networks (DNNs)

Cai [7] proposed a two-stage DNN for laser microphone speech enhancement, separating power and phase

components of the waveform. The model outperformed STFT-based baselines in perceptual evaluation of speech quality (PESQ) and short-time objective intelligibility (STOI). However, it underperformed in log spectral distance (LSD), suggesting limited accuracy in fine spectral reconstruction. The reliance on paired clean and noisy data

also raises questions about generalizability to unseen acoustic conditions.

Convolutional and Recurrent Models

Convolutional neural networks (CNNs) operating on spectrograms have been used for denoising, with Daisuke [22]

demonstrating CNN-based speaker recognition using self-coupling LD microphones. Recurrent neural networks (RNNs) and long short-term memory (LSTM) models capture temporal dependencies in noise, and Cai [7] reported

improved high-frequency reconstruction using LSTMs with cross-entropy loss. While promising, these models face challenges in latency and computational load, making real-time deployment on embedded platforms difficult.

Generative Adversarial Networks (GANs) and Lightweight Models

Speech enhancement GANs (SEGANs) [28] generate clean audio by adversarial training, often producing more

natural-sounding speech than traditional filters. Meanwhile, lightweight RNN-based systems such as RNNoise
[29] combine DSP with small neural networks, enabling real-time noise suppression at low cost. These methods

suggest a pathway toward embedded deployment, but their performance on laser microphone data remains largely unexplored, as most have been validated only on conventional audio datasets.

Traditional filtering remains essential for baseline noise suppression, especially in resource-constrained or low-latency systems. However, their reliance on stationary noise assumptions and rigid filter structures limits performance in complex, real-world acoustic environments. Machine learning models demonstrate superior adaptability and perceptual quality but face challenges of dataset scarcity, computational overhead, and reproducibility. The

2.6. Digital Filtering (Post-ADC)

literature reveals a critical gap: there is no standardised dataset of laser microphone recordings for benchmarking denoising algorithms. As a result, most ML-based studies adapt models from conventional speech enhancement,

which may not capture the unique distortions introduced by optical-acoustic sensing. Bridging this gap will require community-driven datasets and hybrid methods that integrate the interpretability of classical filtering with the adaptability of machine learning.

### 2.6.2 Speech-to-Text Systems

Speech-to-text (STT) systems play a crucial role in forensic and intelligence work, particularly for analyzing

and transcribing covert recordings obtained through hidden microphones, parabolic sensors, or optical systems. Transcription transforms spoken evidence into written form suitable for legal or investigative use, providing a permanent record that can be analyzed linguistically or acoustically [30]. However, conventional manual

transcription—often performed by certified translators or forensic linguists—is time-consuming and vulnerable to human error or perceptual bias, especially when recordings are degraded, multilingual, or captured under challenging acoustic conditions [31].

As Loakes et al. [31] note, covert recordings frequently suffer from overlapping voices, background interference,

or limited frequency response, which complicates manual interpretation and reduces evidential reliability. This has motivated growing forensic interest in Automatic Speech Recognition (ASR) and AI-driven STT systems as

objective tools capable of consistent and scalable transcription. Yet, even advanced ASR systems face persistent challenges such as alignment inaccuracies and the risk of “force-aligning” incorrect transcripts to indistinct speech segments—a critical concern in forensic validation and chain-of-custody integrity.

Modern transcription systems have evolved significantly from analogue audio analyzers to fully AI-driven frameworks capable of synchronized digital processing, real-time captioning, and emotion recognition. Eftekhari [32]

highlights how intelligent STT platforms enhance efficiency in domains such as emergency response and medical diagnostics—capabilities that can be extended to surveillance analysis where rapid transcript generation is essential. Nonetheless, system accuracy remains heavily dependent on acoustic conditions, microphone quality, and training datasets, requiring human verification and linguistic post-editing for evidentiary use.

Comparative evaluations by Matarneh et al. [33] categorize major ASR frameworks—including CMU Sphinx, Kaldi,

HTK, Microsoft Speech API, and Dragon Medical—by their domain suitability. Open-source engines such as Kaldi and CMU Sphinx are favored in research and multilingual applications, while proprietary systems like Google Speech and Dragon Medical excel in domain-specific accuracy and noise resilience. These platforms collectively demonstrate the trade-off between transparency, adaptability, and recognition performance, crucial factors when selecting STT tools for forensic or intelligence contexts.

Beyond classical ASR, end-to-end speech-to-text translation (ST) frameworks have expanded the scope of automated transcription. Chen et al. [34] and Xu et al. [35] identify key advances such as pre-training, data augmentation,

and knowledge distillation—techniques that enhance robustness in low-resource and cross-lingual scenarios typical of real-world surveillance audio. Similarly, Bansal et al. [36] demonstrated that translation models can be trained

directly from raw audio-text pairs using unsupervised term discovery, a promising avenue for multilingual forensic processing where annotated corpora are unavailable.

While technological advances have improved recognition speed and cross-lingual accuracy, transcript readability and evidential clarity remain concerns. Jones et al. [37] observed that automatically generated transcripts are

often harder to read and comprehend than those produced by humans, emphasizing the importance of linguistic

2.6. Digital Filtering (Post-ADC)

post-processing and readability correction before legal submission. Thus, despite their efficiency, current STT systems still require expert review to ensure forensic admissibility and contextual accuracy.

In summary, speech-to-text technology has evolved from experimental recognition systems into a sophisticated toolset for forensic intelligence and surveillance analysis. By integrating traditional acoustic modeling with deep-learning-based transcription, modern systems provide unprecedented scalability and consistency. However, challenges in low-quality audio interpretation, model generalization, and transcript validation continue to limit full automation, underscoring the enduring importance of human oversight in forensic transcription workflows [30], [31], [32], [33], [34], [35], [36], [37].

Table 2.1: Summary of Speech Recognition and Speech-to-Text Methods with Real-World Examples matarneh2017, [38], [39], [40], [41], [42], [43], [44], [45]

System / Method | Model / Ap-proach | Key Features | Strengths / Notes | Examples
Template-Based | Reference template matching [38], [40] | Matches input utterances with stored patterns using dynamic time warping or posterior-based distance met-rics | Simple implementation and interpretable matching; effec-tive for isolated-word recog-nition but limited to small vocabularies and speaker de-pendency | Early IVR sys-tems, CMU Sphinx (legacy)
Knowledge-Based | Rule extrac-tion from linguistic and phonetic fea-tures [33] | Uses manually defined syn-tactic or phonetic rules de-rived from domain data | Interpretable structure, use-ful for specialized domains or low-data scenarios; less scal-able to large vocabularies or continuous speech | Dragon Natu-rallySpeaking (early versions)
Statistical (HMM) | Hidden Markov Mod-els with Gaussian mix-tures [33], [39] | Models temporal variabil-ity and state transitions in speech; MFCC or PLP front-end features | Reliable and robust for real-time ASR; adaptable to new languages via re-training; still forms hybrid back-end in Kaldi and HTK systems | Kaldi, Julius, HTK [42]
Neural Network-Based | DNN / RNN / LSTM acous-tic models [33], [43], [44] | Learns deep hierarchical fea-tures and temporal depen-dencies; enables end-to-end acoustic-to-word mapping | High accuracy for large-vocabulary tasks and real-world speech; effective noise robustness; integration into cloud APIs | Google Speech API, Microsoft Azure Speech [43], [44]
End-to-End Seq2Seq | Encoder–decoder with attention or transform-ers [39], [41] | Directly maps speech wave-forms to text or translation outputs; often pretrained on multilingual corpora | Removes manual alignment and HMM dependency; sup-ports low-resource and mul-tilingual input; strong noise resilience but high compute cost | OpenAI Whis-per, Vosk, Meta SeamlessM4T, SpeechT5 [41]

### 2.6.3 Assessment of Speech-to-Text Models

It is essential to establish objective frameworks for evaluating system performance of STTs. While traditional assessments have focused on qualitative judgments or human transcription accuracy, quantitative metrics such as Word Error Rate (WER), Short-Time Objective Intelligibility (STOI), and Signal-to-Noise Ratio (SNR) now serve as standardized benchmarks for comparing the accuracy, intelligibility, and overall quality of

2.6. Digital Filtering (Post-ADC)

automated transcription systems. These measures are particularly relevant in the context of laser microphone recordings, where acoustic distortions and optical artifacts can significantly affect both intelligibility and recognition accuracy.

Word Error Rate (WER)

Word Error Rate remains the most widely adopted metric for evaluating ASR system performance. WER quantifies transcription accuracy by measuring the minimum number of word-level edits required to transform the hypothesis transcript into the reference transcript. The metric is calculated as:

WER =

S + D + I
N
× 100% | (2.1)

where S represents substitutions, D denotes deletions, I indicates insertions, and N is the total number of words in the reference transcript.

WER provides a normalized measure for comparing recognition systems across datasets and languages. Ali and Renals [46] established foundational methods for WER estimation in modern ASR systems, introducing estimated WER (e-WER) techniques that enable performance prediction without requiring full reference transcripts—an approach particularly valuable in real-time forensic analysis.¹

Recent work by Park et al. [47] and von Neumann et al. [48] refines WER definitions for long-form and multi-

talker scenarios, addressing challenges that frequently arise in extended surveillance or conversational recordings. Meanwhile,Von et al. [48] specifically propose the Diarization-Invariant cpWER (DI-cpWER), a metric designed

to isolate and quantify the effect of speaker attribution errors. Unlike the conventional concatenated minimumpermutation WER (cpWER), which is sensitive to speaker label mismatches, the DI-cpWER corrects these

mismatches to reflect the error rate achievable if speaker labels were perfectly assigned. The difference between cpWER and DI-cpWER thus indicates the proportion of errors arising solely from speaker confusions Itoh et al. Apple Machine Learning Research [49] proposes humanized WER formulations emphasizing readability and accessibility, aligning error measurement more closely with human comprehension. Their solution (human evaluation word error rate)HEWER ignores the use of filler words in its approach different from WER which

ignores punctuation and counts every words that is not identical to the reference as an error.

Short-Time Objective Intelligibility (STOI)

While WER measures textual accuracy, it does not capture perceived speech clarity. The Short-Time Objective Intelligibility (STOI) metric provides a complementary measure focused on the intelligibility of the enhanced speech itself. Developed by Taal et al. [50], [51], STOI evaluates the correlation between clean and processed speech

in the time–frequency domain, yielding scores between 0 and 1, where higher values indicate better intelligibility.

The algorithm divides speech into short frames and computes correlation coefficients between spectral envelopes of the clean (xm(j)) and degraded (ym(j)) signals:

STOI =

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
ρ(xm(j), ym(j)) | (2.2)

where M is the number of frames, J the number of frequency bands, and ρ the correlation coefficient.

1https://github.com/qcri/e-wer

2.7. Environmental and Surface Limitations

STOI has been shown to correlate strongly with subjective listening tests across noise, reverberation, and other degradations. Scores above 0.75 suggest good intelligibility, while values below 0.60 indicate the need for further enhancement. Implementations are available through the MATLAB Audio Toolbox [52] and official open-source resources [53].

Signal-to-Noise Ratio (SNR)

The Signal-to-Noise Ratio (SNR) quantifies the relative strength of the speech signal against background noise, expressed in decibels (dB):
SNR = 10 log10

Psignal
Pnoise
(2.3)

where Psignal and Pnoise denote the power of the clean speech and noise components, respectively.

Ephraim and Malah [54] pioneered a priori SNR estimation, forming the basis of Wiener and MMSE filters used in speech enhancement. Plapous et al. [55] refined these approaches for improved accuracy under non-stationary conditions, while Vondrášek and Pollák [56] demonstrated the influence of voice activity detection (VAD) on

SNR estimation reliability. Input SNR values typically range from –5 dB to 15 dB, improving to 10–30 dB after enhancement—an improvement of roughly 10–20 dB, sufficient for most ASR systems. NIST [57] provides

standardized procedures for measuring SNR consistency across datasets.

Comprehensive Performance Evaluation

As emphasized by Hu and Loizou [58], no single metric reliably captures perceptual quality under all degradation

types. A holistic assessment must therefore combine multiple metrics such as WER, STOI, and SNR, along with subjective listening tests. Rix et al. [59] further standardized perceptual evaluation through PESQ (Perceptual Evaluation of Speech Quality), now widely used for speech quality benchmarking. Interactions between these metrics are nonlinear—systems may achieve high intelligibility (STOI) but still record high WER due to language

model errors, or show SNR gains without corresponding intelligibility improvement due to artifacts. Therefore, multi-metric benchmarking remains essential to guide optimization and ensure reliable performance in forensic and surveillance contexts.

## 2.7 Environmental and Surface Limitations

While the optical and signal processing components of laser microphones have received substantial attention, their performance in real-world environments remains constrained by environmental factors and target surface properties. These limitations are particularly significant because they directly affect the reliability and generalizability of laboratory findings.

### 2.7.1 Surface Reflectivity and Roughness

The accuracy of optical-acoustic transduction depends strongly on the reflective properties of the target surface. Smooth, mirror-like surfaces maximise specular reflection and yield higher signal-to-noise ratios (SNR), whereas rough or diffuse surfaces scatter the incident laser beam, reducing coherence and increasing noise [7]. Rothberg et al. [15] highlighted that speckle effects caused by surface roughness introduce random intensity fluctuations,

complicating phase-based detection schemes such as laser Doppler vibrometry. These effects are particularly problematic for surveillance applications, where the surface cannot be controlled.

2.8. Conclusion

### 2.7.2 Environmental Noise and Turbulence

Environmental factors such as wind, air turbulence, and ambient vibrations impose additional noise sources. For outdoor applications, turbulence alters the refractive index along the beam path, leading to beam wander and amplitude fading [15]. Mechanical vibrations of the laser mount or reflective object also couple into the

acoustic signal, generating low-frequency artefacts. Unlike electronic or optical noise, these disturbances are highly nonstationary, making them difficult to suppress with conventional filtering.

### 2.7.3 Eye Safety and Power Constraints

System performance is further constrained by eye safety regulations. While longer wavelengths (e.g., 1550 nm) allow

higher permissible power levels under IEC laser safety standards, they reduce detection efficiency in silicon-based photodiodes [14]. Conversely, shorter wavelengths (e.g., 633 nm) provide high sensitivity but introduce greater

scattering and potential safety risks. This trade-off forces designers to balance sensitivity, safety, and practicality, often resulting in suboptimal compromises.

The literature consistently acknowledges that environmental and surface limitations pose some of the most significant barriers to the practical deployment of laser microphones. Although controlled experiments often demonstrate promising noise suppression and speech intelligibility, these results rarely translate to uncontrolled settings. Current research gaps include the lack of standardised protocols for testing under turbulence, variable reflectivity, and real-world outdoor conditions. Future work should therefore prioritise hybrid systems that combine optical sensing with auxiliary modalities (e.g., inertial or contact sensors) to ensure robustness against environmental disturbances.

Without addressing these limitations, even the most advanced filtering algorithms cannot guarantee reliable field performance.

## 2.8 Conclusion

This review surveyed the evolution of laser microphones from Bell’s 1880s photophone through Theremin’s 1947 infrared system to contemporary semiconductor implementations achieving sub-nanometer sensitivity [6]. Modern

systems integrate distributed feedback lasers, low-noise transimpedance amplifiers, and digital signal processing, yet performance remains heavily surface- and environment-dependent, with significant sensitivity–robustness–cost trade-offs.

Component selection involves critical design choices: wavelength determines the balance between eye safety (1550 nm), photodetector efficiency (650–850 nm), and environmental robustness [14], [15]. Dual-TIA architectures

enhance ambient light rejection through common-mode suppression, although their experimental validation remains limited. Signal processing spans two paradigms: traditional techniques (FIR filtering, Wiener, spectral subtraction) provide real-time efficiency but assume stationary noise [23], [24], [26], while machine learning (DNNs, RNNs) offers superior adaptability [7], [29] at higher computational cost. Hybrid architectures combining classical preprocessing

with lightweight neural networks represent a promising compromise.

Speech-to-text integration enables objective evaluation via WER, STOI, and SNR [46], [51], [54], revealing non-

linear metric relationships—high STOI does not guarantee low WER, and SNR gains may not directly improve intelligibility [58]. Therefore, comprehensive multi-metric evaluation remains essential for assessing overall system

performance.

Priority research gaps include:

2.8. Conclusion
1. Development of standardized benchmark datasets capturing diverse surfaces, acoustic conditions, and noise profiles.
2. Systematic real-world characterization of performance under turbulence, variable reflectivity, and environmental interference.
3. Quantitative cost–performance analysis to inform economically viable designs.
4. Exploration of hybrid architectures integrating complementary sensing modalities (e.g., inertial sensors) for

enhanced robustness.

In summary, the literature reveals that while individual subsystems—optical, electronic, and algorithmic—have advanced considerably, their integration into a cohesive, low-cost, and field-deployable system remains limited. This project directly addresses these gaps by implementing a dual-TIA receiver, a combined FIR–Wiener–spectral subtraction processing pipeline, and a multi-model ASR evaluation framework. Emphasizing cost-effectiveness (R2000 constraint), open-source reproducibility, and quantitative multi-metric assessment, the ensuing chapters

transition from theoretical exploration to practical realization, demonstrating how laser vibrometry can achieve intelligible, transcribable audio reconstruction within realistic design constraints.

# Chapter 3

# Methodology

This chapter outlines the methodological framework adopted for the design, simulation, and experimental validation of the laser microphone system. The approach is structured into five interdependent stages, ensuring a systematic and iterative development process from conceptualisation to final prototype validation.

Each stage built upon the findings of the previous one to refine both the hardware and signal-processing aspects of the system.

## Stage 1 – System Design and Simulation

The first stage involved the conceptual and analytical design of the laser microphone system. System requirements are defined through an assessment of acoustic sensing principles, optical reflection behaviour, and photodetector response. Then a block-level architecture is developed to establish the interaction between the optical transceiver, the analog front-end, and the digital signal processing (DSP) subsystems.

Optical and electronic subsystems are simulated using LTspice to model expected signal behaviour, frequency response, and noise performance. The simulations provided quantitative insight into the relationship between laser beam modulation and detected voltage variation, enabling the determination of design parameters such as photodiode sensitivity and pre-amplifier gain.

Stage 1.1 – Breadboard Testing and Iteration

Following initial simulations, a series of breadboard prototypes are constructed to validate the theoretical models. The optical alignment, photodiode biasing, and amplifier stages are tested incrementally. Each configuration is evaluated in terms of signal clarity, frequency response, and susceptibility to ambient light interference. The results of this phase informed iterative refinements of the circuit topology and component selection, ensuring system stability before PCB implementation.

## Stage 2 – PCB Design

Once the circuit functionality is verified on the breadboard, the design is translated into a printed circuit board (PCB) using Kicad 9.0. Emphasis is placed on minimising noise coupling through careful component placement,

Figure 3.1: The overview of all the project stages trace routing, and ground-plane segmentation. Design-for-manufacturability (DFM) principles are applied to

ensure compactness and ease of assembly. Failure precautions are implemented at each stage to ensure the overall functionality of the system if one section fails.

## Stage 3 – PCB Testing and Validation

After fabrication and having received the delivery of the PCB, it underwent a comprehensive testing procedure. Continuity tests using U3401A (digit dual display Multimeter) are performed to verify electrical integrity, followed

by subsystem-level functional testing. Signal integrity is assessed using the DS0-X-2002A oscilloscope and spectrum analyser to confirm the expected frequency response and noise floor. Any deviations from simulation results are analysed to identify potential layout or grounding issues, allowing for specific rework where needed.

## Stage 4 – DSP Development and Integration

The fourth stage focused on developing the digital signal-processing algorithms necessary for converting the detected analogue signal into a clear audio output. MATLAB and Python are used to implement and test algorithms, including filtering, noise suppression, and amplitude normalisation. The optimised DSP routines are then implemented on a Python app localised on a PC. Synchronisation between the optical detection hardware and DSP system is verified through controlled acoustic tests.

## Stage 5 – Final Prototype and Validation

In the final stage, the complete laser microphone prototype is assembled, integrating all mechanical, optical, and electronic subsystems. The system is evaluated under controlled acoustic conditions to assess its sensitivity, frequency response, and distortion performance. Results are benchmarked against theoretical predictions and ideal acoustics recovery to verify design validity. Observations from this validation phase informed recommendations for further optimisation and field deployment.

The iterative process employed throughout this research follows a systematic cycle designed to ensure robust validation at each development stage shown. Beginning with a comprehensive literature review, each stage proceeds through its defined objectives before undergoing rigorous testing and validation. At decision points, the system’s performance is evaluated against predetermined requirements. If these requirements are not met, the process loops back to the previous stage for refinement and retesting, incorporating lessons learned to address identified deficiencies. Only upon successful validation does the development advance to the current stage, where the same cycle of implementation, testing, and requirement verification is repeated. This feedback mechanism ensures that design flaws and performance limitations are identified and resolved before progressing to subsequent stages, thereby preventing the propagation of errors through the development pipeline. Should the current stage fail to meet its requirements, the iteration continues until satisfactory performance is achieved, at which point the process advances to the next stage. This structured approach minimises the risk of fundamental design issues emerging late in the development cycle and ensures that each subsystem—from initial simulation through to final prototype validation—performs reliably before being integrated into the complete laser microphone system. The details on validation and testing are provided at each stage.

Ethical Considerations Ethically, all test audio consisted of publicly available material or synthesised speech, with no recordings of private conversations or identifiable individuals. The system was operated exclusively within

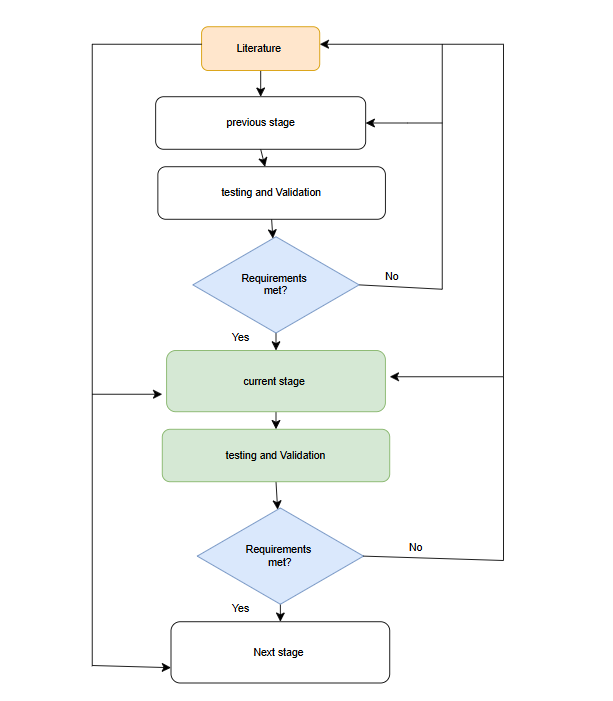
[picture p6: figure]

Figure 3.2: Iterative development flow diagram illustrating the requirement-driven progression through design stages with feedback loops for refinement and validation the university laboratory under controlled conditions, with no field surveillance testing conducted, complying with UCT’s ethical guidelines for engineering projects that do not involve human subjects research or covert monitoring applications.

# Chapter 4

# System Design and Simulation Analysis

This chapter presents the detailed design and simulation analysis of the laser microphone system. The design process is carried out iteratively, where simulation results guide hardware refinement and component selection. The approach ensured that both the optical and electronic subsystems are optimised for performance, stability, and manufacturability. The primary goal is to develop a reliable, low-noise, and compact system capable of reconstructing sound from optical reflections with high fidelity.

## 4.1 Overview

The laser microphone system operates on the principle of detecting sound-induced surface vibrations using an optical beam. A continuous laser is directed onto a reflective surface, and acoustic pressure variations cause minute displacements that modulate the reflected beam’s intensity on the chosen optical receiver. This optical modulation is captured by a photodiode and transformed into an electrical signal, which is then processed through analogue amplification, filtering, and digital signal processing (DSP). The complete system is powered via a standard 5 V

USB supply from the PC, making it portable and compatible with typical laboratory environments.

## 4.2 System Requirements and Specifications

The development of the laser microphone system begins with a clear understanding of its design expectations and operational constraints. These requirements establish the foundation for a reliable and functional system, ensuring that the design objectives are met during both simulation and prototype validation. This section defines the system requirements and corresponding specifications that guided the design process.

### 4.2.1 Requirements

Table 4.1 illustrates the user and functional requirements identified for the laser microphone system.

Table 4.1: Requirements for the Laser Microphone System

REQ-ID | Description
REQ-01 | The system must be low-cost.
REQ-02 | The system must operate using a 5 V DC supply provided via a standard type A USB 2.0 port.
REQ-03 | The system must be capable of capturing sound remotely through a reflected laser beam.
REQ-04 | The recorded audio output must be intelligible and comparable to the reference sound source.
REQ-05 | The system design must require minimal user alignment and setup.
REQ-06 | The complete setup should be compact, portable, and suitable for laboratory-scale testing.

The requirements listed above define the performance expectations of the laser microphone system and form

4.2. System Requirements and Specifications

the foundation for the subsequent specification and design phases. They ensure that the final prototype meets functional, operational, and usability targets while remaining low-cost and reproducible.

### 4.2.2 Specifications

Based on the analysis of the requirements tabulated above, Table 4.2 illustrates the detailed system specifications addressing each requirement, along with the corresponding acceptance criteria that must be met.

Table 4.2: Specifications for the Laser Microphone System

SPEC-ID | Description | REQ-ID | Acceptance Criteria
SP-01 | The system must use a red or infrared laser diode (650 nm–1400 nm) to de-tect sound-induced vibrations from re-flective surfaces at long range. | REQ-03 | Verify that surface vibrations produce measurable signal modulations at the photo receiver output at a minimum of 1 m distance between the receiver and vibrating surface.
SP-02 | The optical receiver must convert reflected light intensity variations into voltage signals using a tran-simpedance amplifier. | REQ-03, REQ-04 | Validate the analogue output for a range of vibration amplitudes and fre-quencies (100–20 000 Hz).
SP-03 | The analogue front-end must provide low-noise amplification and band-pass filtering for 100–18 000 Hz. | REQ-04 | Measure the SNR of the audio file, and it must be within 85% of the SNR of the ideal sound.
SP-04 | The system must interface with a USB sound card for digitisation and PC-based DSP processing. | REQ-02, REQ-04 | Confirm that the recorded signal can be acquired at 44.1 kHz, 16-bit resolu-tion in MATLAB.
SP-05 | MATLAB-based DSP must recon-struct intelligible audio using spectral subtraction and filtering. | REQ-04 | Evaluate processed signal clarity and confirm speech intelligibility above 85%.
SP-06 | All system components must operate on a single 5 V USB power source. | REQ-02 | Measure total current draw and confirm current consumption below 500 mA.
SP-07 | The total prototype cost must not ex-ceed R2000. | REQ-01 | Validate the cost by summing all pur-chased components within the ap-proved bill of materials.

The specifications outlined for the laser microphone system serve as a guide for design and implementation, ensuring that all requirements are met. Each specification is directly traceable to a corresponding requirement, providing measurable performance targets for verification and validation during testing.

4.3. Design Outline

## 4.3 Design Outline

The system design is also structured into three primary domains—optical, analogue, and digital—each fulfilling a specific role in the detection and reconstruction of sound. The optical subsystem provides remote vibration sensing through laser reflection, the analogue front-end ensures low-noise signal conditioning, and the digital signal-processing (DSP) subsystem reconstructs the audio signal through real-time computation. Figure ?? presents

the complete system architecture, highlighting the interaction between these domains.

## 4.4 System Overview

The laser microphone system operates on the principle of optical modulation caused by surface vibrations. When the laser beam reflects off a vibrating surface, the returning light undergoes slight intensity variations proportional to the acoustic signal present on the surface. To extract the embedded information, the reflected beam is detected, converted to an electrical signal, and processed to recover the original sound waveform.

Figure 4.1 illustrates the high-level architecture of the receiver subsystem. The system is divided into three main subsystems:

- Optical and Signal Conditioning Module — captures the reflected light and converts it into a conditioned electrical signal using a photodiode and amplification circuitry.
- Data Acquisition Module — digitises the conditioned analogue signal via a USB sound card or ADC for further processing.
- Digital Signal Processing (DSP) Module — performs demodulation, filtering, and spectral enhancement

to reconstruct intelligible audio from the detected signal.

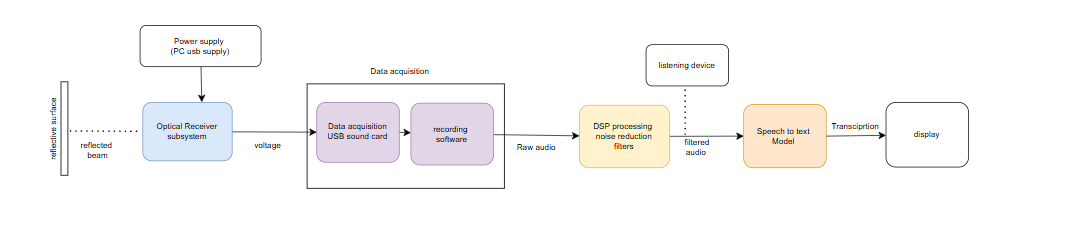
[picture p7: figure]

Figure 4.1: High-level architecture of the laser microphone receiver, showing the optical detection, acquisition, and DSP subsystems.

## 4.5 Hardware Design Process Overview

Following the description of the system design and requirements, it is essential to select hardware components that satisfy the design objectives outlined in Chapter ??, while minimising noise during the retrieval of the modulated signal. This section details the hardware selection process, focusing on component suitability, electrical compatibility, and noise performance.

4.5. Hardware Design Process Overview

Laser Module

A red dot laser module operating in the visible range (λ ≈ 650 nm) is selected as the optical transmitter for this project due to its practicality, visibility, and ease of alignment during laboratory testing. Although infrared (IR)

lasers offer greater discretion for surveillance applications, their invisible beams complicate alignment and safety verification in an experimental setting. The visible red beam, on the other hand, enables precise targeting of the reflective surface and provides immediate visual feedback, significantly reducing setup time and alignment errors.

The selected red dot laser module offers stable optical output power, a compact form factor, and low cost, making it an ideal choice for the prototyping stage of the laser microphone system. Furthermore, the system architecture remains compatible with future adaptation to infrared operation, requiring only replacement of the laser source without major modification to the receiver or signal-processing stages. The datasheets of the following candidate modules are reviewed to evaluate output stability, current consumption, and optical parameters, ensuring compliance with the specifications outlined in Table ??.

To determine the most suitable laser source for the prototype, three candidate transmitters are evaluated in terms of optical performance, electrical compatibility, and practical usability. Table ?? summarises the comparison of these options, highlighting key parameters such as wavelength, output power, operating voltage, and cost.

Table 4.3: Comparison of Laser Transmitter Options

Component / Feature | KY-008 | ROHM RLD65NZX1-00A | BezosMax red laser Pointer
Wavelength | 650 nm (Red) | 663 nm (Red) | 650 nm
Output Power | 5 mW | Up to 10 mW | >5 mW
Beam Range | 18 m under suitable conditions | Medium-range (tens of meters) | Up to 2,500 m
Operating Voltage | 5 V DC | 2.3 V DC typical | USB-C rechargeable
Package / Size | 24mm × 15 mm, 3-pin module | TO-56 metal can, 3-pin | Handheld laser pointer with star cap and USB Type A male connector
cost(ZAR) | 17.00(DIY electronics) | 436.80(RS Components) | 199(takealot)

RLD65NZX1-00A is not used because of the cost and the requirement to build a dedicated laser driver to ensure a

stable output, as this would introduce more complexities into the design. Ky008 and the Bezomax laser pointer are lab tested on their reflectivity at 1 meter distance on a 3mm window pane glass in the setup as described in section section 4.7. ky008 could not be reflected at 1 1-meter distance, but can be reflected 10cm. While the Bezomax laser pointer is effectively reflected, even at 2m. Thus, given that the laser microphone, which requires a long range distance, the primary limitation of the BezosMax pointer is rapid battery depletion during testing. To address this, a 1m female-to-male USB cable is acquired. With the female part connected to the laser, the PC could supply the laser with constant power with a range of motion.

The difference in reflectivity can also be attributed to beam optics. The KY-008 is a bare module without an integrated lens system, so its beam is less uniform and less focused. The BezosMax pointer, in contrast, is packaged as a handheld pointer with built-in optics that produce a well-collimated beam, improving reflection over longer distances. Thus, the bezomax pointer is opted for use, and all the following processes considered it to be the main transmitter.

optical receiver

Based on the selection of the 650 nm laser module, an optical receiver is designed to operate within the laser wavelength and the acoustic frequency range. The optical receiver forms the critical interface between the optical and electrical domains of the laser microphone, converting modulated light reflections into electrical signals for amplification and processing.

4.5. Hardware Design Process Overview

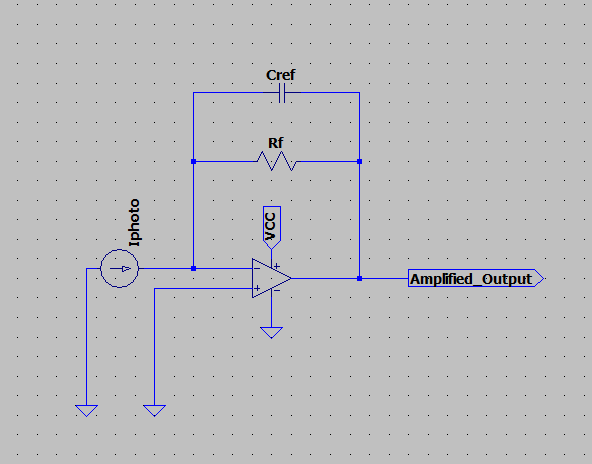
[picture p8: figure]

Figure 4.2: Transimpedance amplifier converting photodiode current into a voltage signal for optical-to-electrical interfacing.

In this design, a silicon photodiode is chosen after a comparative evaluation against a phototransistor. The selected device, a BPW34 photodiode, operates on the internal photoelectric effect, generating a photocurrent linearly proportional to the incident optical power. Its wide spectral sensitivity range (400–1100 nm) and peak responsivity of approximately 0.6 A/W at 650 nm make it well matched to the red laser source. The BPW34’s fast

rise time of about 100 ns provides a bandwidth exceeding 3 MHz—well above the 100 Hz–18 kHz acoustic range of interest—ensuring accurate tracking of vibration-induced optical modulation. Additionally, the photodiode exhibits low intrinsic noise and high linearity, allowing precise demodulation of the optical signal.

Although the photodiode compared to phototransistors it generates lower raw current, it delivers a cleaner, more

linear signal with minimal noise and stable sensitivity over temperature. These characteristics make the BPW34 the optimal choice, providing a balance of sensitivity, fidelity, and simplicity suitable for the low-cost, high-precision requirements of the laser microphone system.

Transimpedance amplifier

In this design, a low-noise operational amplifier is connected in a feedback configuration with a precision resistor. The photodiode is connected to the inverting input of the op-amp, and the feedback resistor determines the gain of the circuit according to the relation as shown below:

Vout = −Iphoto · Rf

where Iphoto is the photocurrent generated by the photodiode and Rf is the feedback resistor. A parallel capacitor across the resistor is often added to stabilise the amplifier and limit high-frequency noise, forming a low-pass filter that prevents oscillations while maintaining bandwidth sufficient to capture acoustic vibrations (100 Hz–18 kHz).

By integrating the TIA immediately after the photodiode, the design maximises signal-to-noise ratio and preserves the fine details of the reflected laser signal, making it a critical component in the laser microphone system.

To improve common-mode rejection and mitigate ambient light interference, a dual-TIA (transimpedance amplifier) configuration is adopted, where two TIAs share a single photodiode input. This approach is inspired by

4.5. Hardware Design Process Overview

the recommendations of Koheron koheron2018, who demonstrated differential TIA designs for enhanced ambient

noise immunity.

The dual-TIA configuration, shown in Figure 4.3, employs two identical transimpedance amplifiers based on LM358 operational amplifiers, both connected to the same photodiode source. In this arrangement, the photocurrent generated by the BPW34 photodiode is fed simultaneously into two amplifier channels that operate in opposite polarities. Each channel converts the incident photocurrent into a voltage signal proportional to the optical intensity, with the outputs being 180° out of phase with respect to each other.

The individual transimpedance stages (U6 and U7) consist of precision feedback resistors (R17, R18) and small compensation capacitors (C11, C12), which together define the gain and frequency stability of each amplifier. The resulting voltages are then AC-coupled through capacitors (C9, C10) to a subsequent differential amplifier stage (U8). The differential amplifier subtracts the two TIA outputs, effectively amplifying the desired modulated signal

component while cancelling any common-mode disturbances present on both channels.

This configuration offers significant performance advantages in optical detection applications. Ambient light and background illumination typically introduce low-frequency or DC photocurrent components that appear identically on both TIA inputs. Since these unwanted signals are common to both channels, they are rejected by the differential amplifier according to its common-mode rejection ratio (CMRR). Consequently, the system primarily responds to

the differential signal originating from laser intensity modulation caused by acoustic vibrations, while suppressing slow variations due to environmental lighting or power supply fluctuations.

To further illustrate the benefits of this approach, Table 4.4 summarises the key differences between a conventional single-TIA configuration and the adopted dual-TIA design.

4.5. Hardware Design Process Overview

Table 4.4: Comparison between Single and Dual Transimpedance Amplifier Configurations

Characteristic | Single TIA Configuration | Dual TIA Configuration
Ambient Light Sensitivity | High — DC and low-frequency ambient light components di-rectly appear at the output. | Strongly reduced; common-mode (ambient) components are cancelled by differential subtrac-tion.
Signal-to-Noise Ratio (SNR) | Limited by ambient fluctuations and amplifier offset drift. | Improved SNR due to common-mode noise rejection and bal-anced signal paths.
Output Offset and Drift | Large DC offset may cause out-put saturation or reduced dy-namic range. | DC offset is largely eliminated through differential operation, maintaining a wide dynamic range.
Circuit Complexity | Simple and low component count. | Slightly more complex; requires component matching and an ad-ditional differential stage.
Response to Modulated Optical Signal | Directly proportional to pho-tocurrent. | Differential gain applied to the modulated component while rejecting background intensity variations.
Practical Suitability for Laser Microphone | Susceptible to environmental light interference and noise. | Provides stable operation and enhanced robustness under vary-ing ambient light conditions.

By implementing this dual-TIA structure, the receiver achieves a higher signal-to-noise ratio and improved stability under varying ambient conditions. The approach also reduces the likelihood of output saturation caused by large DC offsets, ensuring that the dynamic range is reserved for the modulated optical signal. This differential detection technique thus provides a practical and cost-effective method for enhancing noise immunity in the analogue front-end of the laser microphone system, resulting in cleaner signal acquisition and more accurate reconstruction of the acoustic waveform.

### 4.5.1 Digitisation and Processing Hardware Comparison

The digitisation stage is responsible for converting the conditioned analogue signal from the receiver into a digital format suitable for signal processing and analysis. Several hardware options are evaluated based on sampling resolution, ease of integration with the PC-based DSP environment, and overall system cost. Table 4.5 summarises the comparison of the candidate devices considered for the prototype.

The HiFi USB sound card is ultimately selected as the digitisation interface due to its simplicity, compatibility, and cost-effectiveness. Operating at 48 kHz and 16-bit resolution, it provides sufficient bandwidth and dynamic range for the 100 Hz–18 kHz acoustic band of interest. Its plug-and-play functionality allows direct connection to the PC via USB without the need for additional drivers or microcontroller programming, enabling seamless data acquisition in MATLAB.

4.5. Hardware Design Process Overview

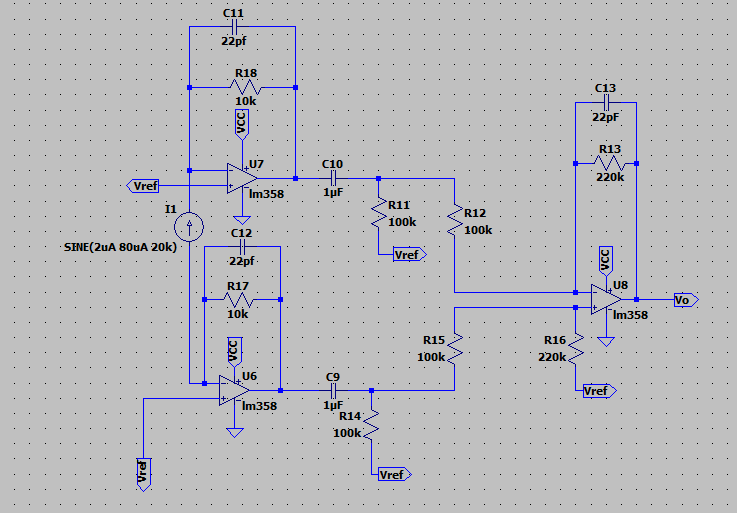
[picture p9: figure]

Figure 4.3: Dual transimpedance amplifier (TIA) configuration used to improve common-mode rejection and reduce ambient light interference

Table 4.5: Comparison of ADC and Processing Interfaces

Device | Sampling Rate / Resolution | Ease of Integration | Approx. Cost (R) | Decision
HiFi USB Sound Card | 48 kHz / 16-bit | Plug-and-play, directly recog-nised by MATLAB and PC audio drivers | 150 | Selected
Raspberry Pi Pico | 500 kS/s / 12-bit ADC | Requires custom firmware and se-rial communication for data trans-fer | 88 | Alternative (future)
Teensy 4.0 + Audio Shield | 44.1 kHz / 16-bit | Excellent audio quality but re-quires complex setup and exceeds cost target | 480 | Rejected (budget)

In contrast, the Raspberry Pi Pico offered higher sampling capability but required custom communication protocols and additional code to handle serial data transfer, complicating integration. The Teensy platform, while capable of studio-grade audio quality, is excluded due to its significantly higher cost and unnecessary processing overhead for this stage of the prototype. Therefore, the USB sound card presented the most practical balance between performance, simplicity, and affordability for the laser microphone system.
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

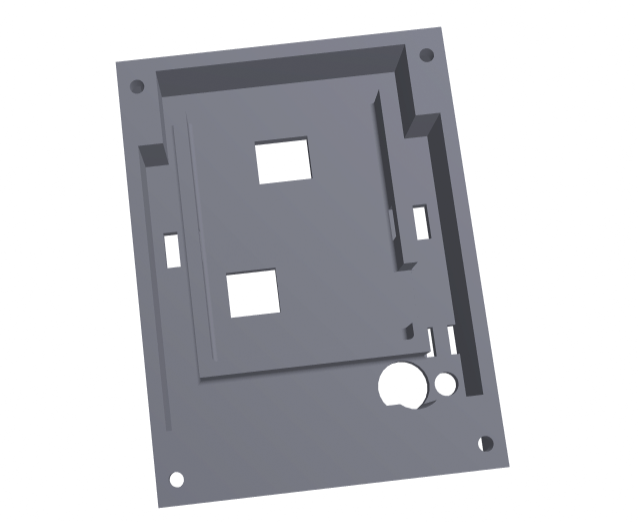
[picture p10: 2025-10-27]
case.png

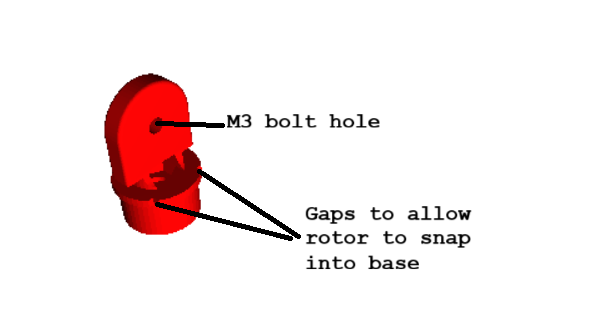
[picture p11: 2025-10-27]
Rotor_annotated.png

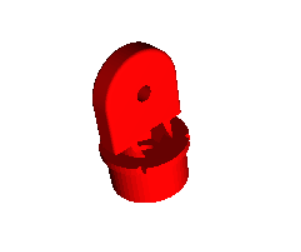
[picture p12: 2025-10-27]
Rotor.png

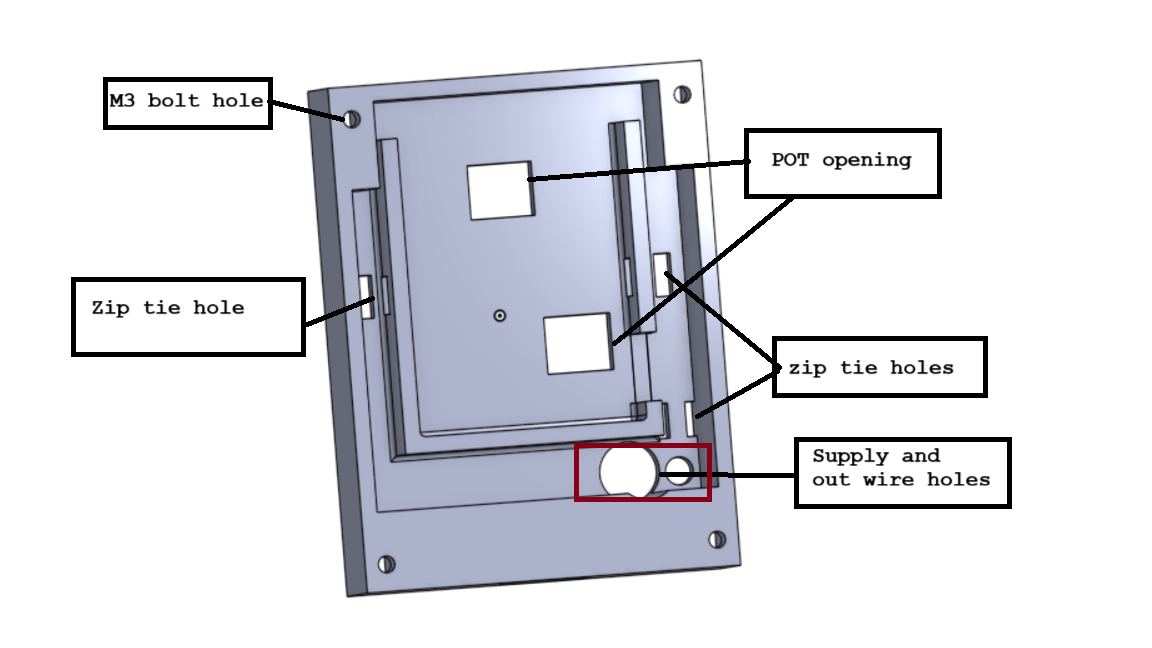
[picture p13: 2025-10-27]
Final_Case.png

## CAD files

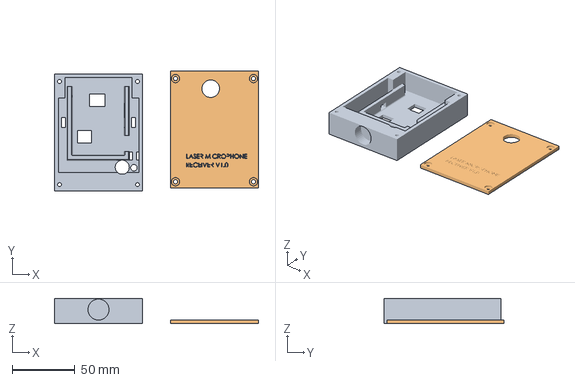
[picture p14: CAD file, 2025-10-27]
casing.3mf
162.2 x 95.3 x 20.0 mm
casing
closing_cover

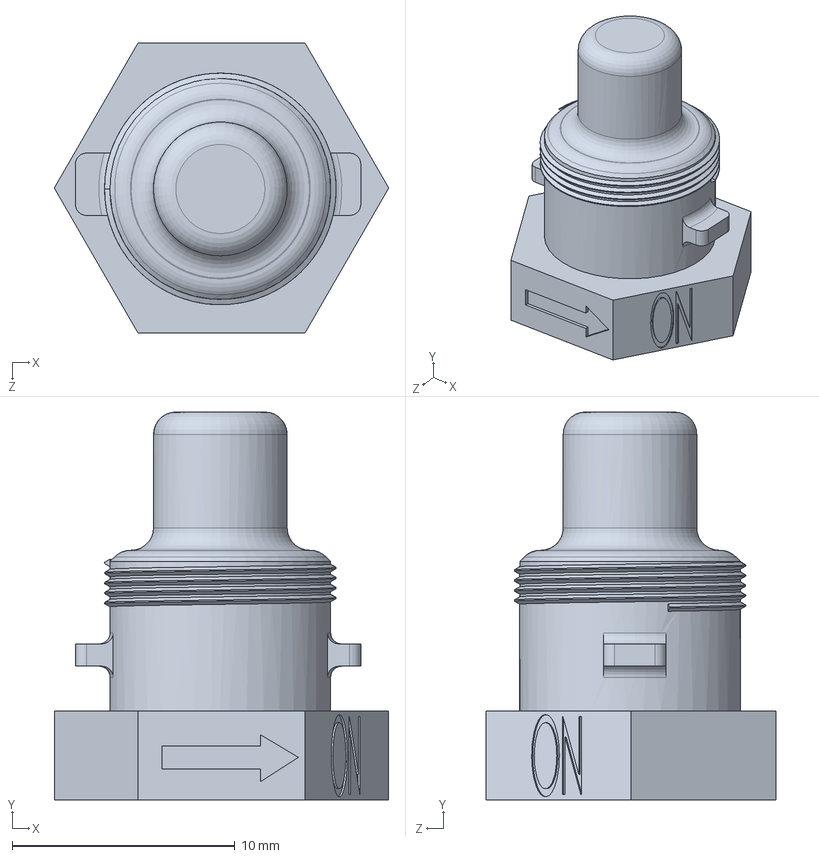
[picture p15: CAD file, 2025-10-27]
button.SLDPRT
15.0 x 17.4 x 13.0 mm

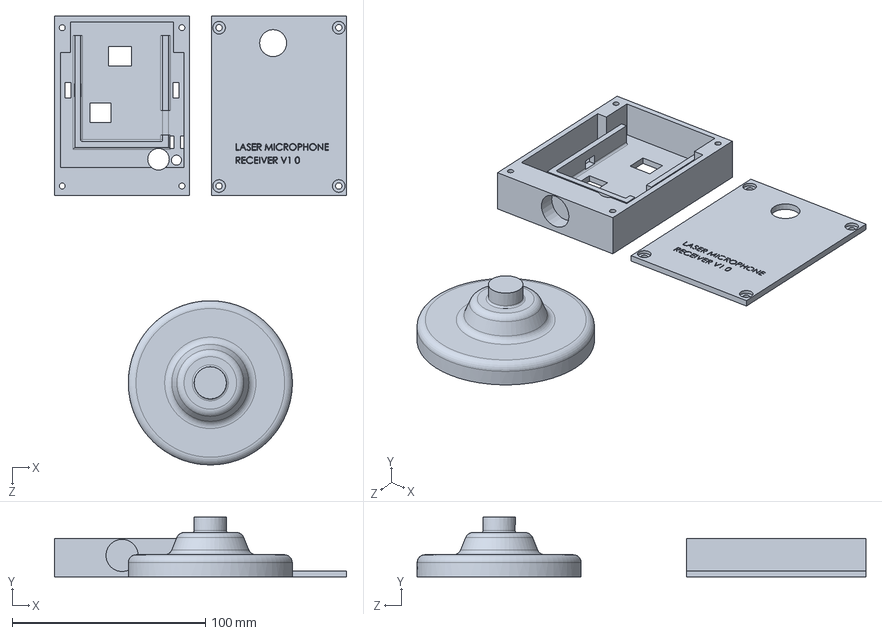
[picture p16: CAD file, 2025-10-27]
receiver_casing.SLDPRT
151.2 x 31.0 x 232.5 mm

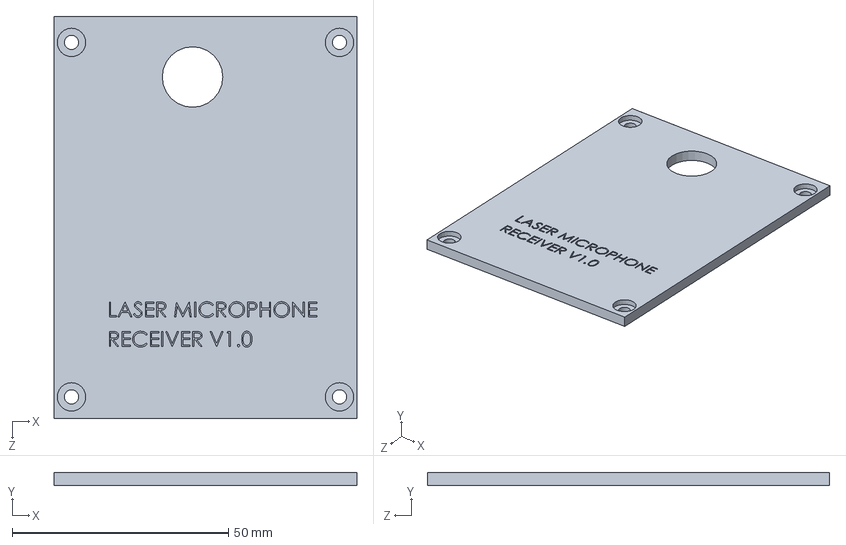
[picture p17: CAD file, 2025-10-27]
closing_cover.SLDPRT
70.0 x 3.00 x 93.0 mm

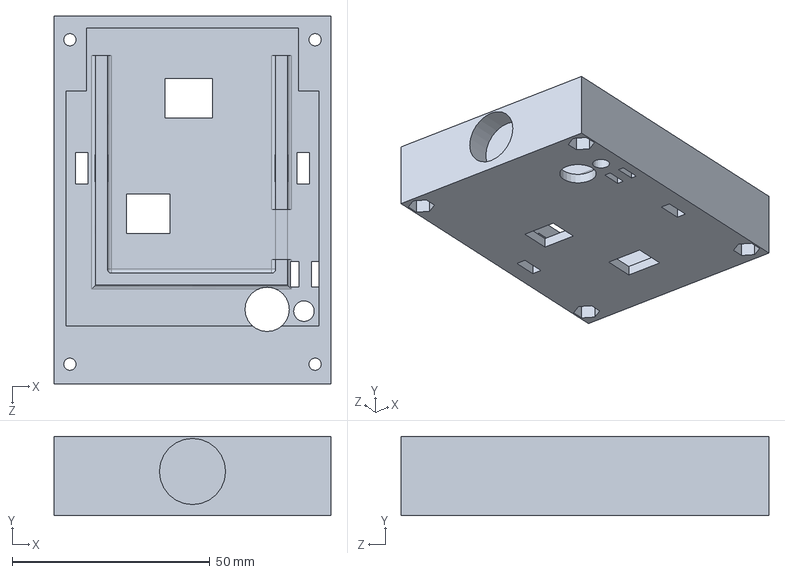
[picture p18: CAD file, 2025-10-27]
case2.SLDPRT
70.0 x 20.0 x 93.0 mm

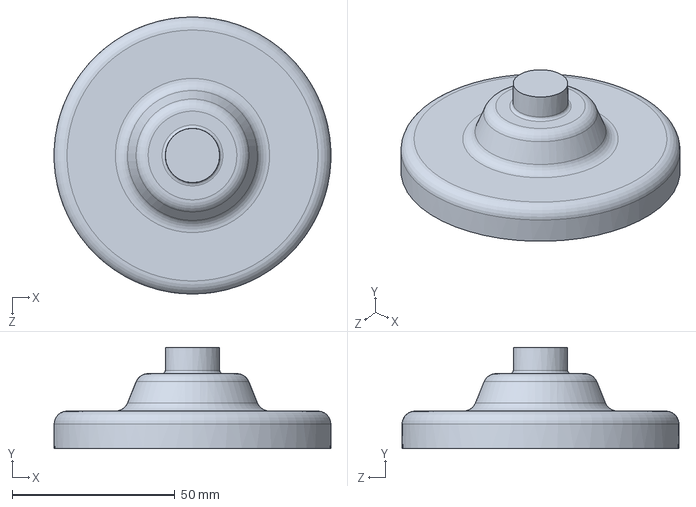
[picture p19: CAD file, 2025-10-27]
base.SLDPRT
85.0 x 31.0 x 85.0 mm

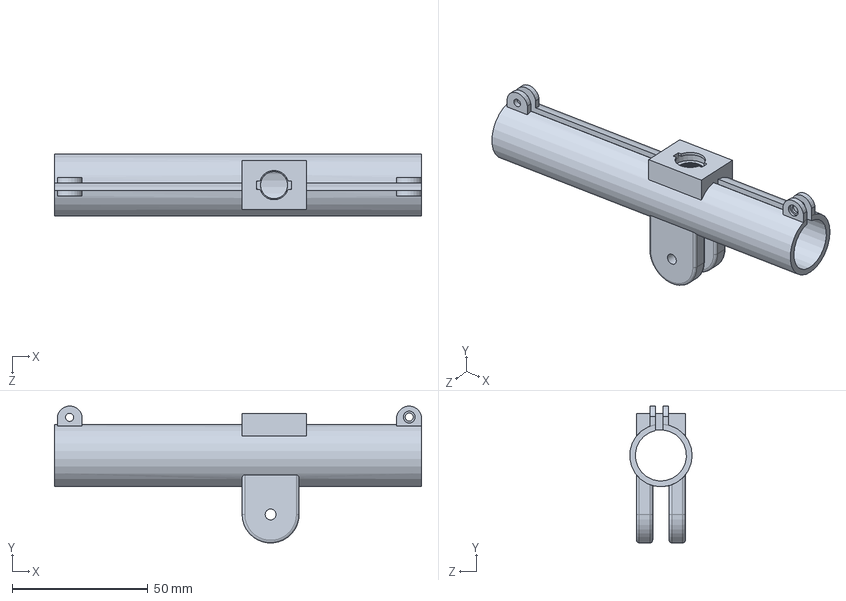
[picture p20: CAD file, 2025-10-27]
hanger_laser.SLDPRT
135.0 x 50.3 x 22.9 mm

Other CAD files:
base.3MF
button.3mf
closing_cover.3MF
hanger_laser.3MF
